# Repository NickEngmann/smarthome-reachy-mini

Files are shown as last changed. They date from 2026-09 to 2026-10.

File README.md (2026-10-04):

# smarthome-reachy-mini

Hardware for putting a smart-home display on a **Pollen Robotics / Hugging Face Reachy Mini**. The display is an **Elecrow CrowPanel Advanced 7" ESP32-P4** (1024×600 IPS touch, ESP32-C6 Wi-Fi 6). It rides on the robot's front belly in a 3D-printed enclosure dressed as denim dungarees.

The display's firmware and software live in the sibling repo **`../smarthome-reachy-mini-display`**.

## System architecture
The display is one part of a local, private assistant that replaces an Echo Show:
- **Reachy Mini** handles listening, speaking, reflexes and gestures.
- A **Jetson AGX Thor** runs speech recognition, a local LLM and speech synthesis.
- **Home Assistant** on a Raspberry Pi 5 keeps timers, weather, music and alerts.
- The **CrowPanel** is an Echo-Show-style dashboard that reads only Home Assistant.

This is the current direction, not final software decisions. It is written up in [`../smarthome-reachy-mini-display/docs/system-architecture.md`](../smarthome-reachy-mini-display/docs/system-architecture.md); the latency design is in [`docs/latency.md`](../smarthome-reachy-mini-display/docs/latency.md) in the same repo.

## Repo map

| Path | What |
|---|---|
| [`hardware/enclosure/`](hardware/enclosure/README.md) | The dungarees enclosure: cadquery source, fit, mesh and printability checks, renders, and **Bambu Studio projects ready to print** (`out/bambu/*.3mf`) |
| [`cad/`](cad/README.md) | Reference models: Reachy Mini body and robot (assembled from Pollen's URDF), Elecrow's official CrowPanel P4 STEP and STL conversions, and two community cases (the ACOS enclosure for the S3 Advance 7", and a two-part case 3MF) |
| `elecrow-crowpanel-advance-7-enclosure-model_files.zip`, `elecrow-panel.3mf` | The original community-case downloads, also unpacked under `cad/community-cases/` |
| [`docs/TODO.md`](docs/TODO.md) | Hardware ideas not built yet, with whatever has already been measured for them. First up: **a hat**, and what the antennas and the head's microphones will and will not allow |

## Print the enclosure
1. Open `hardware/enclosure/out/bambu/reachy-dungarees-tray-cradle.3mf` and `reachy-dungarees-bezel-backstrap.3mf` in Bambu Studio.
2. Load PETG and print. Both projects are set for an X1C with a textured PEI plate, 0.20 mm layers, and no supports.
3. Assemble: board into the tray, bezel snapped on, tray-cradle against the belly, backstrap slid on from behind along the side rails until it stops, then a pin dropped into the top of each side joint (the two pins print on the bezel-backstrap plate).
4. Optional: `reachy-dungarees-bib-straps.3mf` (41 min, 9.1 g, PETG) adds the two shoulder straps. They hang over the robot's own front rim and slide down behind the panel into the pocket the cradle already has, where a spring finger clamps each one against the collar band (v3 — v2 needed hot glue). They change nothing about the three parts above — see the enclosure README's "Bib straps".

Check the enclosure README's Status section before printing: it records the last verified build. It also lists the tolerances, load reasoning and open risks.

## Rebuild from source
The enclosure scripts use cadquery on the ESP-IDF 3.11 interpreter (`python`), with numpy and scipy. Bambu Studio's CLI is used for slicing. See [`hardware/enclosure/README.md`](hardware/enclosure/README.md) for the full command list.

## Licences of included third-party files
- **Reachy Mini meshes:** Pollen Robotics, CC BY-NC-SA 4.0.
- **CrowPanel STEP:** Elecrow, from their GitHub repo, which has no licence file.
- **ACOS enclosure:** Alley Cat / Majestic AV, CC BY-SA 4.0 (attribution required).

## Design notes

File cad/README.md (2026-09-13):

# CAD reference models

Reference geometry for the smarthome Reachy Mini display enclosure. All units are mm unless noted.

## `reachy-mini/` — Pollen Robotics Reachy Mini
Assembled from the per-part STLs and URDF in https://github.com/pollen-robotics/reachy_mini (`src/reachy_mini/descriptions/reachy_mini/urdf/`), at the URDF zero pose. Hardware licence CC BY-NC-SA. No official STEP has been released yet.

- `reachy_mini_body.stl` — body only: foot, turning ring, lower and upper shell
- `reachy_mini_full.stl` — whole robot
- `dimensions.txt` — per-part bounding boxes, plus body radius per 5 mm of height
- `reachy_mini_dimensions.png`, `back_interface.png` — Pollen's official drawings
- `preview.png` — render of the assembly

Frame: +X = front (camera side), +Y = robot's left, Z up, Z = 0 at the table.
Body envelope: 155 × 155 × 185. The shell is a rounded square in section: 155 across the flats, ~164 across the diagonals at z 50–100. The top edge is scalloped and highest at the front (z 184.8). The shell yaws ±180° on the foot (z 0–22, ~114 × 126).
The assembly script lives outside this repo, in `Projects/reachy-mini-cad/assemble.py`.

## `crowpanel-advanced-7in-esp32-p4/` — Elecrow CrowPanel Advanced 7" ESP32-P4 (Amazon B0H5K6W1C3)
- `ESP32-P4-7_0-inch-20251229.stp` — official Elecrow STEP, from https://github.com/Elecrow-RD/CrowPanel-Advanced-7inch-ESP32-P4-HMI-AI-Display-1024x600-IPS-Touch-Screen (`3D file/`)
- `CrowPanel-Advanced-7in-ESP32-P4.stl` — STL conversion (0.05 mm tolerance)
- `CrowPanel-Advanced-7in-ESP32-P4_no-flex-tails.stl` — same, with the flat-drawn LCD/touch flex tails clipped off above z = 53
- `dimensions.txt`, `preview.png`

Frame: X = long axis, Z = short axis, +Y = glass/viewing side, origin at board centre.
- PCB: 176.9 × 104.0 × 1.7
- LCD and touch glass: 164.9 × 100
- Active area: ~154 × 86
- Overall thickness: 17.5 (y −13.8 → +3.7)
- Mounting holes: 4 × Ø3.2 (M3) at x ±85.45, z ±49.0, i.e. **170.9 × 98.0** spacing
- Elecrow's spec lists the outline as 180 × 105, 450 g

## `community-cases/`
- `acos-crowpanel-advance-7-enclosure-s3/` — **Alley Cat "ACOS" enclosure** (Printables 1476807), CC BY-SA 4.0. It was designed for the **ESP32-S3** CrowPanel Advance 7", not the P4. Its board screw pattern (171 × 98) matches the P4's, but the port cutouts may not. Parts: front/center/rear in SMA, USB and insert variants, plus buttons and a `complete.step`; overall 197 × 111 × 25. `printables-1476807-description.pdf` has print settings and the BOM (4× M3×8, 4× M3×12, 8000 mAh LiPo).
- `crowpanel-p4-7in-case-3mf/elecrow-panel.3mf` — user-downloaded two-body case, probably Printables 1689586 ("Elecrow CrowPanel ESP32-P4 7" Case" by BIG_SUNDAR); unverified. Tray 182 × 124.5 × 20 plus a 7 mm lid.

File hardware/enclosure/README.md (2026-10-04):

# Reachy Mini dungarees: a CrowPanel 7" P4 enclosure

This is a three-part (plus two small pins), screwless, 3D-printed enclosure for the **Elecrow CrowPanel Advanced 7" ESP32-P4**. It clamps onto **Reachy Mini's front belly** and is dressed as **denim dungarees**: the display is the bib, and the collar is the waistband. It turns with the body and needs no changes to the robot. The display's software lives in the sibling repo `../smarthome-reachy-mini-display`.

The toolchain follows reMixTape (`reMixTape/re-MixedTape/hardware/enclosure`) and Luna (`luna/luna-hardware/hardware/enclosure_v2`): cadquery scripts, an interference check against the board STEP, mesh and layer checks, a Bambu Studio project writer, and headless slicing with the Bambu Studio CLI.

## Commands
Run these with `python`, the ESP-IDF 3.11 interpreter (cadquery 2.8, numpy, scipy).

```
python shell.py                  # once: Reachy shell proxy -> out/cache/
python enclosure.py              # build + export all parts (~12 min)  [--plain: no dungarees detail]
python collar.py --check-only    # fit checks on the exported STEPs (exit 1 on failure)
python check_mesh.py             # every exported STL watertight
python islands.py                # layer scan: floating islands (what the slicer calls "floating regions")
python islands.py --overhangs    # layer scan: cantilever/bridge regions with locations
python bambu.py --slice          # out/bambu/*.3mf + overhang audit + Bambu Studio CLI slice (time, grams, warnings)
python probe.py                  # diagnostic: re-slice with supports on critical regions, report where they touch
python render.py                 # out/render/*.png
python overalls.py [--check]     # the two optional bib straps (~1 min); --check-only for the fits
python render_overalls.py        # out/render/overalls-*.png
```
After a build, everything below `enclosure.py` reads only its exports, so the checks can run side by side. Run `bambu.py --slice` on its own, though: with the other checks competing for the CPU, a slice of the tray-cradle ran past 25 minutes. `python enclosure.py --check` builds and checks in one go (slower).

## Parts

| Part | Prints | Function | Dungarees detail |
|---|---|---|---|
| **bezel** | face down | Window over the active area. A full-depth top wall holds the **microSD slot**. A snap lip hangs from a shelf on the plate on three sides, with 45° bumps on the two ends. Oval bosses hold the board down, with slot sockets for the tray's locating pegs. | Dashed stitch round the bib, two bib buttons above the screen, and a heart below it. All are engraved, because a face-down print can't have raised detail. |
| **tray-cradle** | upright | The tray has **2× USB-C openings** sized for a plug's overmold and a **switch slot** on one end. The floor has **BOOT/RESET pin holes** plus LED and mic holes. Four standoffs carry **locating pegs** through the board's M3 holes, and relief channels above the USB-C windows let the connectors slide down past the wall. Behind the tray, ribs bear on the belly and the front half of the waistband ends, on each side, in a plate with two rails, a stop, and a cap with the pin hole. | A strap, buckle and engraved button on each end of the bib, a stitched waistband, belt loops and a rolled cuff. |
| **backstrap** | upright | The rest of the collar. At each side, a tongue slides onto the plate's two rails and is locked by a pin dropped through the cap into a boss on the tongue (v0.6). Three **spring tabs** preload the collar, and a **cable gutter** runs along the bottom. | Crossed back straps with edge stitching and teardrop buttons, two back pockets, a waistband with belt loops, and side buttons. The gutter doubles as the cuff. |
| **pins ×2** | head down | The side joints' locks (v0.6): Ø4 × 25 mm with an 8 mm head, dropped through the tray-cradle's cap into the backstrap's boss on each side. They print on the bezel-backstrap plate. | Copper-coloured in the renders, like jeans rivets; print them in any colour. |
| **bib-strap ×2** | on its side | **Optional, cosmetic.** Hangs over the robot's own front rim, runs down the outside of the shell, and drops into the gap behind the display, where a foot fills the pocket between two of the cradle's ribs and a spring finger clamps it in place. The other three parts are untouched. | The two shoulder straps of the dungarees, 14 × 2.1 mm with edge stitching, completing the crossed straps already moulded on the backstrap. |

## Bib straps

Two small clip-on prints (`overalls.py`), added after the first three were done. They are what makes
the robot read as *wearing* the dungarees rather than carrying a bib: from the front a strap comes
over each shoulder and disappears behind the panel. Nothing touches the bib's face, and nothing
about the bezel, tray-cradle or backstrap changes — lift the straps off and the enclosure is exactly
as it was.

```
python overalls.py [--plain]         # build and export the pair (~1 min)  [--plain: no stitching]
python overalls.py --check-only      # fit checks against the exported STEPs
python render_overalls.py            # 3-D views + sections -> out/render/overalls-*.png
python render_overalls.py --section  # just the sections (seconds: no 3-D painting)
```

`overalls-section*.png` are the pictures that actually show the fit: every part cut by a plane just
off the strap's centre and drawn filled, so the rim hook on the shell's top edge, the 1.5 mm the run
stands off the body and the spring finger's nub pressed into the collar band are geometry rather
than a claim. A 3-D render of a 2 mm strap against a curved shell cannot show a 1 mm gap. There is no tight
3-D close-up of either hook for the same reason: `render.py` depth-sorts one collection by centroid,
which breaks down at close range on the shell's coarse triangles.

Each strap is five lofted pieces unioned, sliced every 1 mm so each slice follows the body at its
own Y.

| Piece | What it does |
|---|---|
| rim hook | A loose C over the shell's top edge: a 4.5 mm slot over a ~2 mm rim, reaching 3 mm down inside. Deliberately loose — a tight slot on a rim known only from CAD is a reprint, and the foot is what holds the strap. |
| shell run | Inner face at `SHELL_CLR` (1.5 mm) off the body's front, from z 150 up to the rim. |
| gap run | Leaves the shell at z 152 and leans forward into the gap behind the panel. |
| **tongue** | Fills the slot between two of the cradle's ribs (20.0 in 20.80), 0.40 off the tray's back wall, down to 0.4 mm above the collar band's top edge (Z 124.4). Locates the strap side to side and stops it dropping. |
| **spring finger** | Outboard half only (|Y| 37.5…47.5). A 1.68 mm blade on down the tray's back wall into the slot between the wall and the collar band, to Z 92, with a nub at Z 104 pressing the band. This is what **holds** the strap. |

**v3 (2026-09-30): why the finger.** v2 was printed, and the owner had to hot-glue it in. Its two
shoulders sat on the rib tops and a short tongue hung in the slot — that *located* the strap but
nothing *held* it: there is no downward-facing ledge in the pocket to hook under, and a 3 g strap
on a turning robot walks out. The owner's sketch ran the foot on down behind the panel; v3 does that
and adds a spring, because depth alone still would not hold anything. The nub is modelled 1.2 mm
into the band: the strap first moves 0.40 forward until the tongue bears on the tray's back wall,
and the other 0.8 bends the finger. So the strap is **clamped between two faces of the tray-cradle
itself** and holds by friction. In this print orientation the finger bends along its layers, not
across them — the strong way for a printed spring.

**Where it can go, and why** (robot frame, all measured):

- **The mount is a pocket that was already there.** The ribs at |Y| 25 and 50 (4.2 thick) leave a
  slot **27.10…47.90**, 20.80 wide. Behind the tray's back wall, between those ribs, the free depth
  is 6.7 mm (inboard) to 15.7 mm (outboard) above Z 124, where the shell is what is behind it. Below
  Z 124 the collar band comes in: **1.3 mm** deep inboard, **8.8** outboard, and waisted, narrowest at
  about Z 108. Nothing was added to the cradle, and nothing about it changed.
- **Only the outboard half takes a spring.** Inboard of |Y| 37.5 the waist is under 3.95 mm, and the
  finger needs 3.28 (1.6 to bend into plus 1.68 of blade). There the tongue alone stops on the
  band's top edge.
- **The band is our own part, so it is exact.** `overalls.band_x` sections the same proxy
  `collar.band()` is made from; it agrees with an exact section of the exported STEP to 0.000 mm.
  The exported *STL* — which is what the slicer prints — sits up to **0.28 mm** inside it at the nub
  (collar.py's STL export uses cadquery's default relative tolerance, so its chords are coarse). The
  preload was raised from 0.6 to 0.8 for exactly that, and the check reports both.
- **The strap is flush with the foot's OUTBOARD edge**, centred on |Y| 40.5 (v2: inboard, 31.5).
  The finger only fits outboard, and in the print the outboard edge is the one on the plate — see
  "Print checks" below.
- **The microSD is not a constraint here.** It opens through the bezel's top wall at |Y| 62…76, well
  outboard of the strap. It *was* the constraint for the rejected front-clip version.
- **Head clearance.** Above the front rim the whole robot stays inside X 41.5…43.2 (full mesh,
  z 185…196) while the rim itself is at X 51…55 — about 12 mm of clear space just inside it. The
  measured distance from the rim hook to anything above z 184 and inboard of X 46 is **7.52 mm**.
  That is Pollen's CAD in the URDF zero pose, **not a measured head sweep**: check it on the robot.

**Rejected on the way**, so it is not tried again: straps clipped to the *front* of the bib and
rising above the display. The display's top corners sit 43 mm in front of the body, so such a strap
either spans that gap as a strut or stops in mid-air — three variants were built and rendered, and
none read as a strap from the side. Straps hanging *below* the display have nowhere to go either:
the enclosure's cuff ends at z 30 and the robot's turning foot starts at z 22, and the foot does not
yaw with the body.

## Printing (Bambu Lab X1C)

The three projects are ready to open in Bambu Studio: `out/bambu/*.3mf`. Settings start from your saved X1C project (`bambu/project_settings.json`, taken from luna-hardware): 0.4 mm nozzle, textured PEI, 0.20 mm Standard. Filament is Bambu's own **PETG Basic @BBL X1C** preset.

| Project | Plate | Per-part settings |
|---|---|---|
| `reachy-dungarees-tray-cradle.3mf` | the tray-cradle upright, as it sits on the robot | 5 mm outer brim |
| `reachy-dungarees-bezel-backstrap.3mf` | the bezel face down (textured PEI gives the bib a fabric-like finish), with the backstrap upright and turned 90° beside it | backstrap: 5 mm outer brim |
| `reachy-dungarees-bib-straps.3mf` | both bib straps on their sides, profile flat on the plate and the Y width as the print Z (each turned so **its own** flush edge is down) | 8 mm outer brim each; first layer 25 mm/s at 255 °C, textured plate 80 °C for the first layer and 75 °C after (adhesion — see below) |

`bambu.py --only <substring>` writes and slices just the projects whose name matches, so a change
to one plate does not re-time the others.

Common process settings:
- **Walls and infill:** 3 walls (the collar band is solid), 5 top and 4 bottom layers, 20 % gyroid.
- **Seam and ironing:** aligned seams, no ironing.
- **Supports:** none anywhere.
- **Elephant foot:** 0.15 mm compensation, so the engraving and the joint's sliding faces stay clean.
- **Bib straps, first-layer adhesion (2026-09-30).** The first v3 print would not stay on the plate
  and the PETG built up on the nozzle, with dry filament (6 % in the box), flow calibration and bed
  levelling all on. Each strap stands on a 284 mm² footprint of thin perimeters, so a line that
  does not bond gets dragged onto the nozzle. That plate alone now prints its first layer at
  25 mm/s (was 50, and 105 for its infill) and 255 °C (the preset's 245 was the coldest layer of the
  print), on a textured plate at 80 °C for the first layer and 75 °C after (preset 70), with an 8 mm
  brim (was 5). Before changing anything, wash the plate with dish soap and water and brush the
  nozzle clean while hot; if it still lifts, add a thin layer of glue stick. The straps have since been
  printed and work (owner, 2026-09-30).

Latest CLI slice:

| Project | Time | PETG | Supports | Slicer warning |
|---|---|---|---|---|
| tray-cradle (v0.6) | 5 h 14 | 162.5 g | none | none |
| bezel + backstrap + 2 joint pins (v0.6) | 4 h 00 | 124.1 g | none | none |
| bib straps (both, v3) | 41 min | 9.1 g | none | none |

**Colour:** a denim-blue PETG. With an AMS, add a height-range filament change on the upright parts for a brown cuff (z 0–4) and waistband (z 32–48 on the plate).

### Print checks and what they changed
Every geometry change is checked four ways: the fit check, `check_mesh.py`, `islands.py` (floating islands, then overhang regions), and a Bambu Studio CLI slice. `probe.py` turns support on for critical regions only and reports where the slicer puts it, which is how its warnings were traced to a part and a height. Fixes made for printing:

- **Bezel lip shelf.** The lip used to hang from the parting plane with a 2.4 mm gap to the plate, held only by the top wall and bosses. Face down, it would have printed as one long bridge in mid-air. It now hangs from a shelf on the plate.
- **BOOT/RESET flex tabs** (since replaced by pin holes, see v0.5). Rooted at the side, their lower edge was a 10 mm cantilever over the slit; that was the tray-cradle's slicer warning.
- **Spring tabs.** The slot and the tab close at the top in a 45° point instead of a flat top slit. The flat slit's roof was a 15 mm curved bridge, 2.5 mm thick with air on both faces, and Bambu Studio flagged it as a "floating cantilever" on the backstrap. `bisect_backstrap.py` found it in two rounds:
  - Round 1: of six variants with one feature group removed, only the one without springs sliced clean.
  - Round 2: flat springs without their nubs still warned, while gable-topped springs with nubs sliced clean.

  The back belt loops moved to 150° and 210° to clear the points.
- **Side buttons.** They are sunk 1 mm into the tongue and shaped as teardrops. At 0.3 mm deep their lowest layers floated; that was the backstrap's "floating regions" warning.
- **Other 45° undersides:** joint hooks (with windows 0.6 mm taller to clear them), teardrop strap buttons, pointed strap ends, a half step under the belt loops, pocket points, overmold recess roofs, and a wedge under the buckle frame. Buckle buttons are now engraved.
- **Mesh fixes:** the collar band stops 0.4 mm behind the tray back, and the tray-end straps no longer touch the button or the tray top. Each of these left faces that only touched, which meshed with non-manifold edges.
- **Fit review before the first print (v0.4).**
  - **Board location:** the locating pegs moved from the bezel to the tray standoffs. With the pegs on the bezel, the board could float ±1.1 mm while hidden pegs, which capture only about 0.7 mm, had to find its holes.
  - **USB-C:** relief channels added above the windows. The shells stood 0.1 mm from the wall while the board went in.
  - **Clearances:** boss-to-board gap 0.2 → 0.4, top-edge clearance 1.5 → 2.0 and collar-to-shell 1.5 (was 1.0).
  - **Snap engagement:** bump engagement 0.45 → 0.40.
  - **Flexures:** slits 0.84 → 1.0 with 45° pointed tops on every flexure; BOOT/RESET tabs thinned to 0.84 mm (about 12 N → 4 N).
  - **Spring nubs:** chamfered on all four sides.
  - **New checks:** `collar.py --check-only` now also checks the assembly paths, not only final positions: the board lifted out of the tray, the tray-cradle backed off the belly, and the backstrap pulled back off the robot and the tray-cradle.
- **Independent fit review (v0.5).** A second reviewer went over v0.4 for anything that would force a reprint. Changes:
  - **Snap bumps:** the bottom bumps are gone. The tray's bottom wall is fused to the cradle filler and can't flex, so a bump there would have strained the lip about 15 %; the bottom lip now only locates. There are five bumps on the two end walls instead (z ±40 and 0 on the right, clear of the USB-C openings and the switch). Both faces are 45°, so the bezel pulls off without prying. The pockets let the bezel lift 0.3 mm (was 0.6).
  - **BOOT/RESET:** Ø3 pin holes with a countersink, pressed with a paperclip. The flex tabs bent across the layer lines at 4–6 % strain, and a pointed slot top left a 0.7 mm web between the two tabs.
  - **USB-C:** the overmold opening (14 × 8.2) runs through the whole wall, so a plug seats fully. The blind recess stopped the overmold 0.8 mm short and left a 0.1 mm web.
  - **Pegs and sockets:** pegs go 1.4 mm past the board (was 2.4). The bezel sockets are 3.4 × 4.2 slots in 5.0 × 5.8 oval bosses. Face down, the bezel shrinks in its own plane while the upright tray's hole pitch doesn't, so round sockets could have ridden up onto the peg points. The boss-to-board gap is back to 0.2: the board thickness was already in the stack-up.
  - **Spring preload:** the nubs reach 1.2 mm plus the play the collar loses as it seats (1.9 mm at the back, 1.55 mm at 120°/240°). Tabs are 1.26 thick and 25 mm long, so the remaining 1.2 mm is about 0.6 % strain.
  - **microSD:** the slot is 12 × 1.6 with a 45° lead-in, so a card can't drop into the case (was 13.4 × 3.2).
  - **Mics:** Ø2.0 teardrop holes (Ø1.2 prints closed).
  - **Lead-ins:** a 0.4 mm chamfer on the bezel lip's free edge, and 0.8 mm chamfers where the tongue meets the strip. The joint pull lips are 0.84 mm proud (was 1.68): only 0.6 mm of lift releases a hook.
  - **Mesh:** the right back strap's edge stitches ended 0.1 mm inside its button and tore the mesh (794 open edges). They now stop 1.5 mm above it. Waistband stitch dashes keep clear of the spring slots.
  - **Checks:** the path sweeps now run the backstrap 100 mm back and the tray-cradle 60 mm off the belly in finer steps, and add the bezel lifted off the tray and board.
- **Plate placement.** The print STLs are set on the plate by their tessellated vertices. OCC's bounding box of the lofted collar was loose, and the STLs floated.

## Load: why it stays put
- **The load is small.** The display (≤450 g) plus the enclosure (~260 g PETG) sits about 20 mm in front of where the ribs bear on the belly. Stopping it tipping forward takes only about 2 N at the collar top.
- **It can't slide.** The collar runs from z 30 to z 124, across the belly's widest ring (r 77.4 at z 60). It is 3 mm narrower above (r 74.3 at z 120) and 4 mm narrower below (r 73.4 at z 30), so it can't pass the bulge either way.
- **The side joints are a rail-and-pin slide lock (v0.6).** v0.5's flex-tab hooks never clicked when printed and the joint had to be glued (owner, 2026-09-30); nothing in v0.6 has to flex.
  - Each side of the tray-cradle ends in a 2.1 mm plate with two rails (z 70 and 100) running along x. The backstrap's 2.94 mm tongue has matching grooves on its inner face, open at its front edge. A 2 mm funnel at each groove's mouth and a 45° taper on each rail's rear end let a rail find its groove from 2 mm out of line. The rails set the tongue's height and keep it on the plate.
  - The backstrap slides forward until the tongue's front edge meets a stop on the tray-cradle. There the two halves of a vertical hole line up: through a cap on the tray-cradle, above the band, and down into a boss on the tongue.
  - A Ø4 PETG pin dropped into that hole on each side is the lock. The collar's pull (the spring nubs push the backstrap back) goes through the pins, in shear. Pull the pins to take the backstrap off.
  - The rails are trapezoids, not dovetails, because of the upright print. A dovetail groove's roof would start at the tongue's face with nothing under it, a floating sliver the length of the groove. The tongue still can't leave its plate: the whole backstrap would have to move sideways, and its other tongue is up against the other plate.
  - Every joint surface is still extruded along x, so the backstrap slides straight on.
- **Spring preload.** Three U-slot spring tabs press their nubs into the shell. They reach 1.2 mm plus the play the collar loses as it seats, so about 1.2 mm of preload remains once seated. The nubs have 45° sides all round, so they ride up onto the shell as the backstrap slides on instead of catching on an edge. The ribs seat on the belly, and the collar's 1.5 mm clearance never becomes rattle.
- **Remaining limit:** at full body yaw, the display's front corners sweep a radius of about 135 mm, and the extra mass makes body turns slower.

## Tolerances: Bambu X1C, 0.4 mm nozzle, 0.20 mm layers, PETG
Every fit is one of these classes (`geom.py`). Walls are whole line widths (`lines(n)` × 0.42 mm), and heights stacked in a part's print Z are whole layers (`layers()`).

| Class | Value | Used for |
|---|---|---|
| `FIT_SNAP` | 0.40 / side | Bezel lip to tray wall (reMixTape printed 0.2 on this printer; +0.2 wiggle room). Bumps are 0.80 with 45° faces both ways, so they engage 0.40 past the wall face, as on reMixTape. Pockets are +0.3 deep and +1.6 wide. |
| `FIT_SLIDE` | 0.40 / side | Faces that slide past each other |
| `FIT_JOINT` | 0.50 / side | The side joint (v0.6): tongue over the side plate, each rail in its groove (normal to every face), the tongue's boss under the tray-cradle's cap. `FIT_SLIDE` + 0.1, because these are 94 mm tall, thin, curved walls printed upright, which warp more than the bezel lip `FIT_SLIDE` was proven on, and v0.5's 0.40 joint never went together. The pin locks the joint, so play in the rails costs nothing. |
| Joint pin | Ø4.0 pin in a Ø4.8 vertical hole | 0.4 a side, so a pin drops in even when the two parts sit 0.4 mm out of line sideways. The stop leaves the two halves of the hole 0.2 past alignment, well inside that. |
| `FIT_Z` | 0.40 (2 layers) | Any gap across layers: glass to bezel plate, lip to PCB, tray top to bezel top wall |
| `FIT_CATCH` | 0.30 | Play at the bezel's snap catch face |
| `HOLE_H_EXTRA` | +0.30 | Holes lying flat in an upright print get a teardrop roof; pins lying flat are teardrops, point down. |
| Locating pegs | Ø2.4 teardrop pins on the tray standoffs (point clipped to R1.45, 1.4 mm past the board, 45° tip); 3.4 × 4.2 slot sockets (long in z) in 5.0 × 5.8 oval bezel bosses | 0.4 / side in the board's Ø3.2 holes. The board sits on its pegs before the bezel goes on, so nothing has to find a hidden hole. The slots absorb the face-down bezel's in-plane shrink. |
| Boss to board | 0.2 (1 layer) | Holds the board down without rattle |
| Board to wall | 0.75 / 1.1 / 2.0 | Sides / USB-C end (plus 0.6 × 9.4 mm relief channels above the USB-C openings, so the connectors, which stand 1.0 mm past the board edge, slide past the wall) / top edge (the flex cables wrap it; was 1.5) |
| Flexure slits | 1.0, 45° pointed tops | Spring tabs: no bridged slit roof sits above a flexure where it could sag and fuse (was 0.84) |
| Shell | 1.5 collar, 0.4 ribs | The shell is Pollen's CAD mesh, not measured on the robot, and a tight collar would mean a reprint (was 1.0). The ribs set the position and the springs remove the play. |
| Openings | USB-C 14 × 8.2 through the wall (R2.2), switch 11 × 5.6, microSD 12 × 1.6 with a 0.8 lead-in, BOOT/RESET Ø3.0 (countersunk Ø4.6), mics Ø2.0 teardrop | |
| Lead-ins | 0.4 × 45° on the bezel lip's free edge; 0.8 × 45° on the side plate's rear outer edge and the tongue's front inner edge; 2.0 × 45° funnels at the groove mouths and 2.0 × 45° tapers on the rails' rear ends; 0.6 countersink on the pin holes and chamfer on the pin tips | |
| Walls | tray 2.1 (5 lines), collar 2.52 (6), tongue 2.94 (7), side plate 2.1 (5), ribs 4.2 (10); 1.68 (4) round each pin hole | |
| Detail, upright | proud 0.84 / 1.26 / 1.68; grooves 0.84 × 0.5 deep; stitch dashes 0.8 tall (4 layers); every underside at 45° or steeper | |
| Detail, bezel face | engraved 1.0 wide × 0.6 deep | |

## Assembly
1. Lower the board, glass up, onto the tray's four locating pegs. Start at the USB-C end, so the connectors slide down the relief channels into their windows. The board then sits on its standoffs without moving.
2. Press the bezel on at the bench, before the tray-cradle goes on the robot, until the bumps click. Its boss sockets drop over the peg tips. To open it, pull it straight off: the bumps are 45° both ways. The notch at the bottom centre gives a fingernail a start.
3. Put the tray-cradle against Reachy's belly. The front half of the waistband slides on from the front.
4. Slide the backstrap on from behind, level, so the tongues pass outside the tray-cradle's side plates. The grooves' funnels catch the rails; push it forward until the tongues stop (the spring nubs drag on the shell on the way). Holding it there, drop a pin into the hole on top of each side, head up.
5. To take it off, pull the two pins and slide the backstrap back.
6. **Bib straps, if you printed them.** Last, and by hand. Slide each one down the back of the
   tray, finger first, into the slot between the ribs — the chamfers find the slot — and keep
   pushing down along the tray's back wall. The nub rides over the collar band's top edge (the finger
   bends about 1.3 mm) and the strap stops when the tongue reaches the band. The rim hook drops over
   the shell's front rim on the way down. To remove, pull it straight up along the tray's back wall.
   They come off before the bezel does.

Cable:
- **Outside power:** plug either USB-C port directly.
- **From Reachy:** lay the cable in the back gutter and down to the foot port, with slack for the body's ±180° yaw.

## Frames
- **Board frame B** is Elecrow's STEP frame: x long, +y is the glass side, z is up.
- **Robot frame R**: +X front, +Y robot's left, Z up, 0 at the table.
- The transform is R = T(X0,0,Z0)·Ry(−6°)·Rz(−90°)·B. `placement()` puts the tray's lowest back edge at z 30, with the tray back 2.5 mm from the shell at the closest point. Board centre: robot X 97.4, Z 86.3.

## Status (2026-09-30, v0.6: rail-and-pin side joints, not yet printed)
v0.5 was printed. Its bezel, tray and collar fit, but its side joints never clicked: the hooks on
the tongues' hidden inner faces never caught in the strip's windows, and the joint had to be glued
(owner). v0.6 replaces the joint with rails, a stop and a drop-in pin on each side. Everything else
is unchanged. The run was `enclosure.py --check`, then `collar.py --check-only` (after fixing one
check), `check_mesh.py`, `islands.py` (both modes) and `render.py`, then `bambu.py --only … --slice`
on each plate on its own. **Everything passes, and both plates slice with no warnings and no supports.**

| Part | Volume | Robot-frame extent (mm) | Checks |
|---|---|---|---|
| bezel | 26.0 cm³ | x 74.7…107.4, y −91.3…91.6, z 31.8…142.5 | unchanged; clear of all 55 board solids; watertight |
| tray-cradle | 144.6 cm³ | x −16.0…103.1, y −92.6…92.9, z 30.0…139.6 | clear of board; watertight; no floating islands |
| backstrap | 82.8 cm³ | x −86.5…11.2, y ±88.2, z 30.0…134.3 | watertight; no floating islands |
| pins (2) | 0.8 cm³ | x −6.0…2.0, y ±88.1, z 112.6…139.6 (as fitted) | watertight; no islands, no overhang regions |

- **Fit check: passed.** 0.000 mm³ for bezel/tray, tray-cradle/backstrap, bezel/backstrap, each part against the shell, and the pins against both parts. The spring nubs overlap the shell by 119.7 mm³ (was 82.6), because they now also reach across the pin's 0.8 mm of play.
- **Assembly paths: passed.** Board and bezel as before, and the tray-cradle backs 1–60 mm off the belly. The backstrap pulls 0.5–100 mm back along the rails, past the shell and the tray-cradle, with 0.000 mm³ at every step.
- **Positive controls.** These prove the zero readings above can see contact at all:
  - Pushed 0.4 mm forward of seated, the backstrap meets the stop (80.7 mm³).
  - A rod 0.3 mm wider than the pin hole hits both parts (59.2 mm³ tray-cradle, 169.6 mm³ backstrap), so the pin really passes through both.
  - The pins lift 2–30 mm straight out without touching anything.
- **Mesh check: passed.** All twelve STLs (as modelled and as printed, the pins and bib straps included) have 0 open edges and 100 % normals.
- **Island scan: clean** on every part. In the overhang scan, the tray-cradle's regions are the same nine ≤1.8 mm ledges as v0.5. The backstrap has one 0.8 mm-reach, 1.2 mm² region at each lower groove's mouth, and the slicer did not flag it.
- **One check fixed on the way.** The "pin passes through the part" control first grew the *pin* by 0.3 mm. That still fits a Ø4.8 hole, so it read 0 and failed. It now grows the *hole* by 0.3 mm.

| Project | Time | PETG | Supports | Slicer warnings |
|---|---|---|---|---|
| `reachy-dungarees-tray-cradle.3mf` | 5 h 14 | 162.5 g | none | none |
| `reachy-dungarees-bezel-backstrap.3mf` (with the two pins) | 4 h 00 | 124.1 g | none | none |

Total: about 9 h 14 and 287 g of PETG (v0.5: 8 h 34, 266 g). Both plates must be reprinted: both halves of the joint changed.

## Previous status (2026-09-13, v0.5, printed; side joints did not work)
Final run after the independent fit review (`enclosure.py`, then `collar.py --check-only`, `check_mesh.py`, `islands.py`, `bambu.py` and `render.py`, then `bambu.py --slice` on its own): **everything passes, and both plates slice with no warnings and no supports.**

| Part | Volume | Robot-frame extent (mm) | Checks |
|---|---|---|---|
| bezel | 26.0 cm³ | x 74.7…107.4, y −91.3…91.6, z 31.8…142.5 | clear of all 55 board solids; watertight; no floating islands |
| tray-cradle | 134.9 cm³ | x −16.0…103.1, y −92.6…92.9, z 30.0…139.6 | clear of board; watertight; no floating islands |
| backstrap | 73.5 cm³ | x −86.5…11.2, y ±84.2, z 30.0…125.0 | watertight; no floating islands, no cantilever or bridge regions |

- **Fit check: passed.** Overlaps are 0.000 mm³ for bezel/tray, tray-cradle/backstrap (the hooks sit in their windows), bezel/backstrap, and each part against the shell. The spring nubs' 82.6 mm³ overlap with the shell is the intended preload plus the seating play.
- **Assembly paths: passed** at every step: the board lifted 0.5–16 mm out of the tray, the bezel (bumps removed) lifted 0.5–8 mm off the tray and board, the tray-cradle backed 1–60 mm off the belly, and the backstrap pulled 1–100 mm back past the shell and the tray-cradle.
- **Mesh check: passed.** All six STLs (as modelled and as printed) have 0 open edges and 100 % consistent normals.
- **Island scan: clean** on all three parts. The overhang scan's remaining regions are short bridges (1–6 mm: the microSD slot roof, the pry notch, loop steps), which PETG prints unsupported.

| Project | Time | PETG | Supports | Slicer warnings |
|---|---|---|---|---|
| `reachy-dungarees-tray-cradle.3mf` | 4 h 52 | 152 g | none | none |
| `reachy-dungarees-bezel-backstrap.3mf` | 3 h 42 | 114 g | none | none |

Total: about 8 h 34 and 266 g of PETG.

### Bib straps (2026-09-30, v3 — PRINTED and working, no glue (owner, 2026-09-30); v2 needed hot glue)
Added without touching the three parts above: `overalls.py`, then `overalls.py --check-only`,
`check_mesh.py`, `islands.py`, `islands.py --overhangs`, `bambu.py --only bib-straps --slice`.
**Everything passes and the plate slices with no warnings and no supports.**

| Part | Volume | Robot-frame extent (mm) | Checks |
|---|---|---|---|
| bib-strap-left | 4.01 cm³ | x 44.2…78.1, y 27.5…47.5, z 92.0…183.7 | watertight; no floating islands |
| bib-strap-right | 4.01 cm³ | mirrored in y | identical — it is the left one mirrored, not a second build |

- **Fit check: passed**, with the nub (the intended preload) taken off first: 0.000 mm³ against
  the bezel, the tray-cradle and the backstrap on both sides, and 0.000 mm³ against the shell proxy
  below z 139. The nub itself is **33.92 mm³** into the collar band on each side.
- **The spring**, per 1 mm slice across the finger: presses **0.80 mm** once seated against the
  band as designed, **0.54–0.73 mm** against the band as printed (its STL). Going in, the finger bends
  at most **1.27 mm** of the 1.60 it has, ~0.58 % strain at the root (1.68 thick, 23.4 mm lever;
  PETG's stiffness is an estimate).
- **Assembly path: passed.** The strap, nub off, moved 1–50 mm out along the tray's back wall:
  0.000 mm³ against every part and 0 points inside the shell wall at every step, both sides.
- **Against the body above the display**, measured point-to-triangle on Pollen's mesh: the run's
  closest approach is **0.81 mm** (0 of 3,616 points inside the shell wall) and the rim hook's is
  **0.64 mm** (0 of 924). The rim hook to anything above z 184 and inboard of X 46 is **7.52 mm**.
  (The run is closer than v2's 1.23 because the strap moved 9 mm outboard; its floor is 0.20.)
- **Mesh check: passed.** All four strap STLs, 0 open edges, 100 % normals.
- **Island scan: clean.** 57 mm² over 45° and 284 mm² on the plate per strap. `islands.py
  --overhangs` lists one 21.7 mm² "bridge" per strap at print z 9.7, and it is the checker's own
  artefact: layer 9.5 lies exactly on a loft station (|Y| 38.0), where the section drops part of
  the gap run (6,011 raster cells there, ~6,585 at 9.49 and 9.51), so the next layer looks unsupported.
  Bambu's slice has no warning.
- **Sections**: `overalls-section.png` (rim hook to finger tip, one closed loop),
  `overalls-section-foot.png` (the finger and its nub in the band), `overalls-section-tongue.png`
  (inboard, the tongue over the band's top edge), and `overalls-cutaway*.png` in 3-D.

**Two check bugs found on the way, worth not repeating.** The right side's cradle clip came back
from OCC *empty* for whole-number bounds (0.0 mm³ against 13,953 on the left), with no error, so the
right strap "passed" against nothing; the clip is off-grid now and the check fails if a clip is
empty. And a nub-removal tool traced along the nub's own ramps left slivers of both ramps behind,
read as 0.72 mm³ of interference; the tool is now a generous block behind the blade.

**Print checks and what they changed (bib straps).** The part prints as a prism extruded along
robot Y, so **robot Y is the print's vertical** — which inverts the intuition about overhangs. v2
cost two rounds, and v3 kept the lesson (strap, tongue and finger are all flush with the OUTBOARD
edge, which goes on the plate, and the part only loses material going up):

- **The foot is 26 mm wide and the strap 14.** Centred, the strap's whole outline — the run and
  the rim hook, 50 mm of it — began 6 mm above the plate with nothing under it: "floating
  cantilever", 214 mm² of overhang and **20 mm² on the plate**. The strap is now flush with the
  foot's inboard edge, so every outline starts at the plate and the part only loses material going
  up: 44 mm² of overhang, 135 mm² on the plate. Each side is turned so its own flush edge is down.
- **The tongue's side taper was 81° in the part and 8° in the print.** A side that drops 10 mm over
  1.5 mm of Y looks nearly vertical in CAD; in the print it crosses 10 mm of plate while the nozzle
  rises 1.5. Still a cantilever, 8.4 mm of reach. The tongue is now a 45° wedge — 1 mm of drop per
  1 mm of width, 6 mm deep, the full 20 mm across at the rib plane and 8 mm at the bottom.

Neither showed up in `islands.py`, which reported CLEAN both times: it finds regions with nothing
at all beneath them, and these had a sliver of contact. The slicer's own warning found both.

| Project | Time | PETG | Supports | Slicer warnings |
|---|---|---|---|---|
| `reachy-dungarees-bib-straps.3mf` (v3) | 41 min | 9.1 g | none | none |

**2026-09-20, handover check.** `check_mesh.py` re-run against the exports exactly as they stand:
all six STLs pass, 0 open edges, normals 100 % (backstrap 74.69 cm³, bezel 25.99, tray-cradle
135.34). The printable results are now **committed** - `out/print/*.stl`, `out/bambu/*.3mf` and
`out/render/*.png` - so the repo can be printed from without a 12-minute rebuild; `out/step`,
`out/stl` and the slicer diagnostics stay out of git, as `.gitignore` says. Nothing was reprinted or
re-sliced, and v0.5 still has never been printed.

## Open risks — check on the first print
- **Collar and spring feel.** If the backstrap is too hard to slide on, reduce `PRELOAD`; if the collar is loose, raise it.
- **Side joint (v0.6), not yet printed.** Every sliding face has 0.5 mm of clearance (`FIT_JOINT`) and the pin 0.4 a side, chosen for warp in the tall upright walls, not measured. If the tongues bind on the rails, raise `FIT_JOINT` by 0.1. If the pin holes don't line up when the tongue is at its stop, the stop is `STOP_X`. The pins hold by gravity; if one ever works up, a drop of glue on its head is fine, because the pin is the only part you take out.
- **Slide switch (MST22D18G2):** the actuator sits 1.35 mm inside the board edge, so it needs a fingernail or pen tip. A captive slider cap would be a v2.
- **microSD** is push-push, about 4 mm inside the wall, so a pen tip may be needed.
- **BOOT/RESET** are pressed through Ø3 pin holes with a paperclip or SIM tool.
- **Bezel retention.** Five 45° bumps hold the bezel by friction and flex, not by a hard catch. If it comes off too easily, raise `BUMP_D` by 0.1.
- **Mics:** their port side isn't known, so there are holes front and back.
- **The optional camera module** isn't accommodated.
- **Antennas:** by Pollen's sleep-pose drawing, the antennas pass about 14 mm outside the collar top. Check this on the robot.
- **Reachy's USB-C output:** check it supplies enough current for the display before relying on it.
- **Bib straps and the head.** The rim hook sits 7.52 mm from anything above the rim *in the URDF
  zero pose*. The head moves on its Stewart platform and this has not been checked against a real
  sweep. Watch it once with the straps on before leaving them there; if the head does come near,
  `RIM_DN` and `RIM_SLOT` set how far the hook reaches inside the rim. The front rim is the highest
  point of the body (z 184.8, against 139 at the sides), which is the reason to expect it is fine.
- **Bib strap retention (v3).** Printed and holding without glue (owner, 2026-09-30). v3 is held by the spring finger's friction, and
  how much it presses is the one number printing can move: 0.80 mm as designed, 0.54–0.73 against
  the tray-cradle's printed mesh, before any print tolerance. If a strap still lifts out,
  raise `FINGER_PRELOAD` by 0.2. The check fails once the bend going in passes 1.4 of the finger's
  1.6 mm of room. If a strap is too hard to push home, lower it by 0.2. If a foot will not
  enter the slot, `FOOT_W` (20.0 in a 20.80 slot) is the number to shave. PETG's stiffness here
  (~2 GPa) is an estimate, not a datasheet figure.
- **The straps assume the shell's real rim matches Pollen's mesh.** The slot is 4.5 mm over a rim
  measured at ~2 mm for exactly that reason, but a much thicker rim would stop the hook seating.

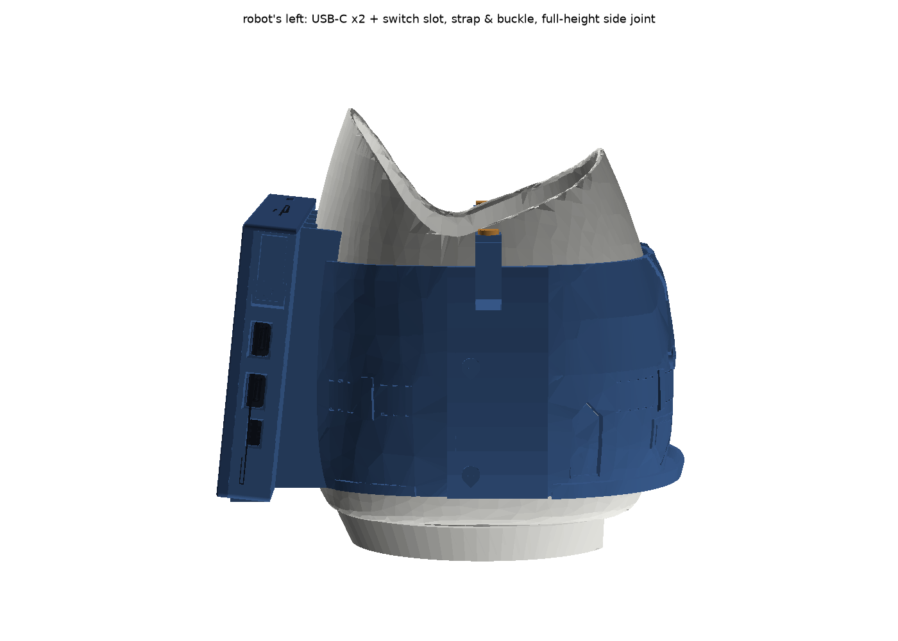
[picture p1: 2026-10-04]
hardware/enclosure/out/render/side-usb.png

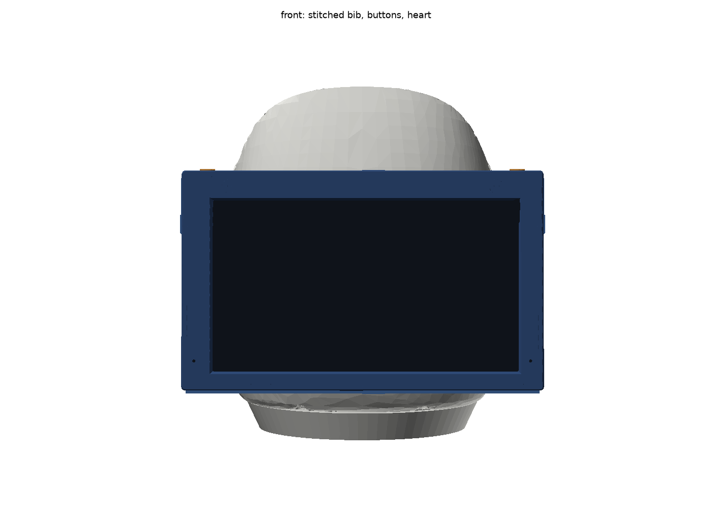
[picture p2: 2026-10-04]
hardware/enclosure/out/render/front.png

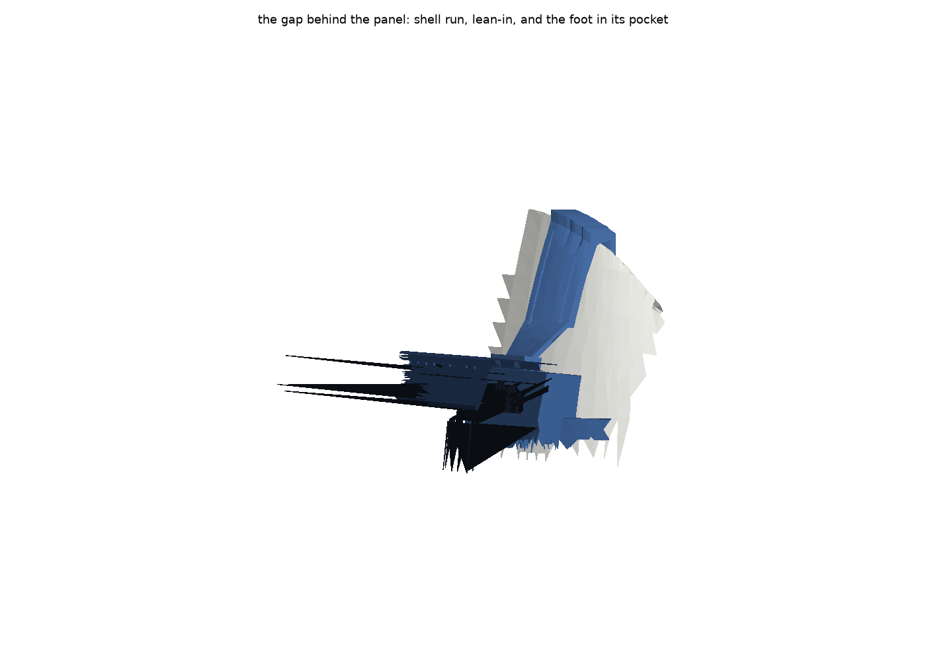
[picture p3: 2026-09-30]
hardware/enclosure/out/render/overalls-gap.png

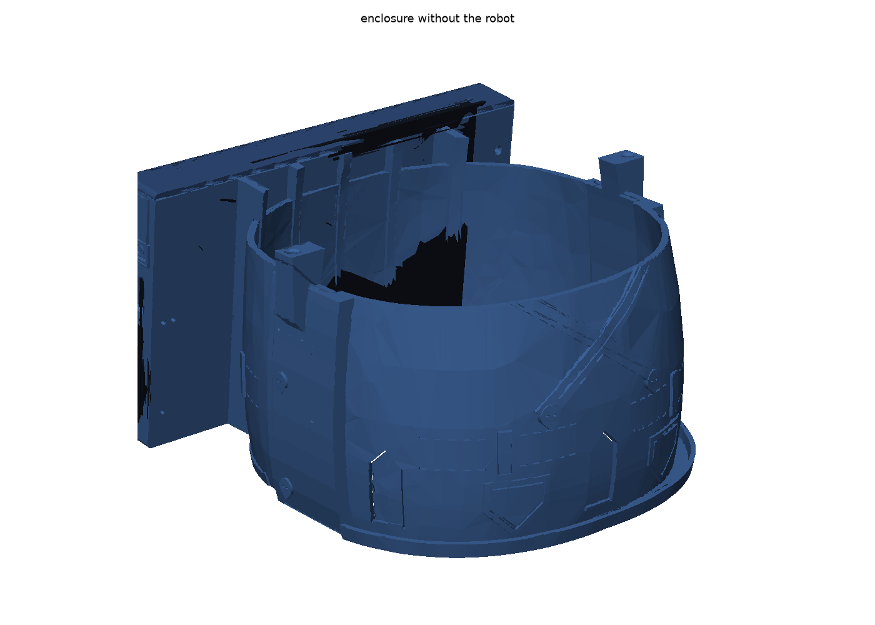
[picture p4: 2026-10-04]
hardware/enclosure/out/render/enclosure-only.png

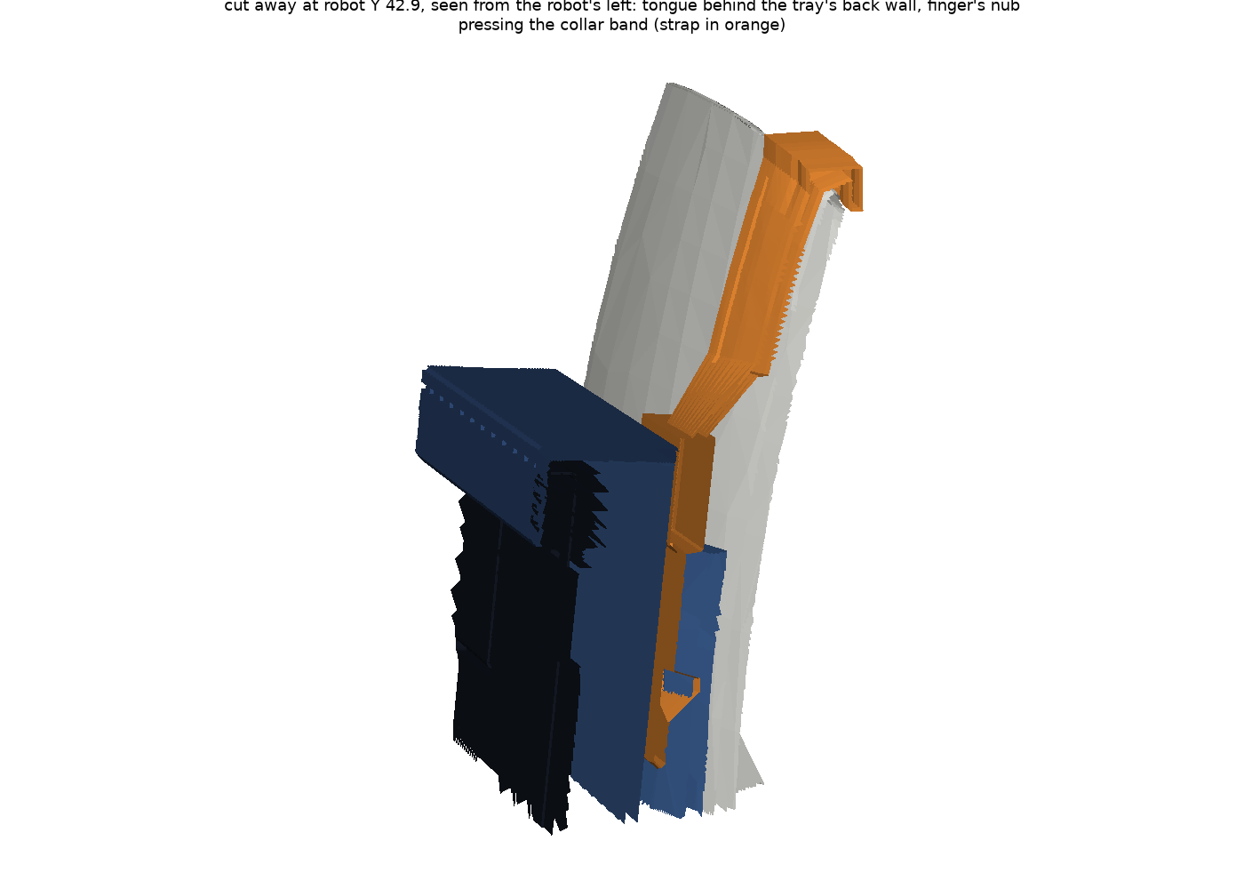
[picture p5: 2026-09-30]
hardware/enclosure/out/render/overalls-cutaway.png

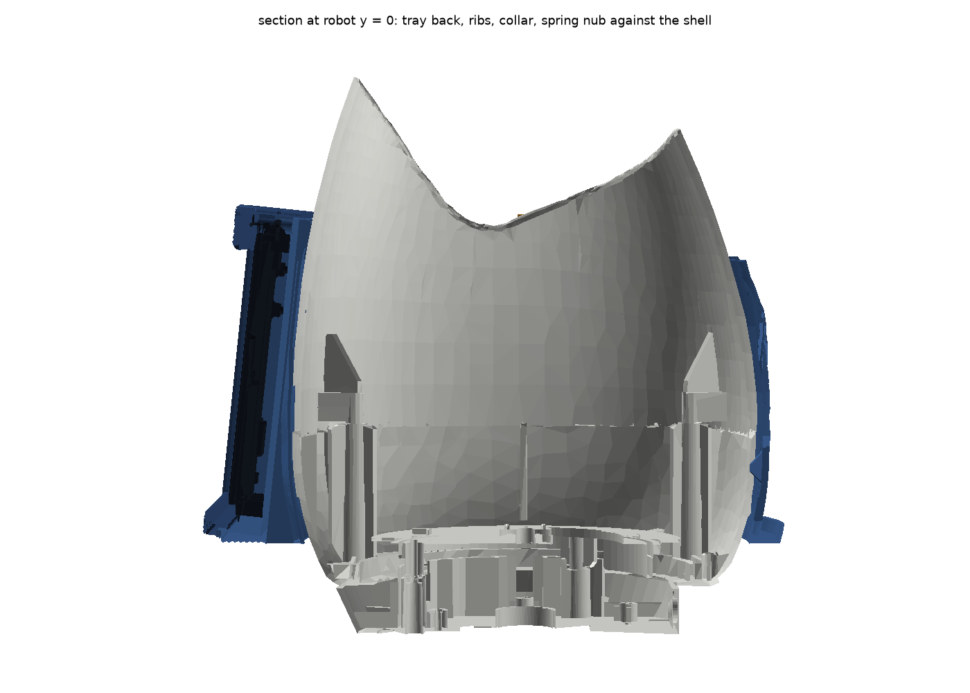
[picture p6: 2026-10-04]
hardware/enclosure/out/render/section.png

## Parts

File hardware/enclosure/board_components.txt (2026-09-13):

AS-AG638A32M1-25 -> AS-AG638A32M1-25                         size   12.50 x  11.00 x   25.25  x[  -6.25,   6.25] y[ -7.30,  3.70] z[ -68.75, -43.50]
=>[0:1:1:10] -> SOLID                                        size  176.90 x   1.70 x  104.00  x[ -88.45,  88.45] y[ -5.70, -4.00] z[ -52.00,  52.00]
U4_CONN-SMD_4P-P2_00 -> U4_CONN-SMD_4P-P2_00                 size   12.00 x   8.40 x    6.21  x[  42.45,  54.45] y[-13.80, -5.40] z[ -50.01, -43.80]
U4_CONN-SMD_4P-P2_00 -> U4_CONN-SMD_4P-P2_00                 size   12.00 x   8.40 x    6.21  x[  64.45,  76.45] y[-13.80, -5.40] z[ -50.01, -43.80]
=>[0:1:1:3] -> SOLID                                         size  164.90 x   3.50 x  155.00  x[ -82.45,  82.45] y[ -3.50,  0.00] z[ -50.00, 105.00]
=>[0:1:1:6] -> SOLID                                         size  164.90 x   1.50 x  200.50  x[ -82.45,  82.45] y[  0.50,  2.00] z[ -50.00, 150.50]
=>[0:1:1:4] -> COMPOUND                                      size  160.90 x   4.88 x   98.50  x[ -80.45,  80.45] y[ -5.70, -0.82] z[ -48.00,  50.50]
=>[0:1:1:7] -> COMPOUND                                      size  160.90 x   7.50 x   99.00  x[ -80.45,  80.45] y[ -5.70,  1.80] z[ -48.00,  51.00]
FPC1_FPC-SMD_P0_50-24P_QCHF-SM -> FPC1_FPC-SMD_P0_50-24P_QCH size   15.60 x   2.01 x    5.80  x[  -7.80,   7.80] y[ -7.66, -5.65] z[ -46.36, -40.56]
=>[0:1:1:11] -> COMPOUND                                     size   51.81 x   8.53 x   93.53  x[ -44.46,   7.34] y[ -6.71,  1.81] z[ -42.51,  51.01]
7CUN-TP-XIAN -> 7CUN-TP-XIAN                                 size   14.00 x   7.90 x   93.70  x[ -44.45, -30.45] y[ -5.90,  2.00] z[ -42.50,  51.20]
MIC-SMD_6P-L4_7-W3_8-P1_65-TL_M -> MIC-SMD_6P-L4_7-W3_8-P1_6 size    4.72 x   1.26 x    3.76  x[ -87.45, -82.73] y[ -6.96, -5.70] z[ -42.00, -38.24]
MIC-SMD_6P-L4_7-W3_8-P1_65-TL_M -> MIC-SMD_6P-L4_7-W3_8-P1_6 size    4.72 x   1.26 x    3.76  x[  82.73,  87.45] y[ -6.96, -5.70] z[ -42.00, -38.24]
WIFIM-SMD_61P-L16_6-W13_2-P0_80 -> WIFIM-SMD_61P-L16_6-W13_2 size   16.60 x   2.51 x   13.20  x[  71.85,  88.45] y[ -8.11, -5.60] z[ -32.00, -18.80]
SW-SMD_MST22D18G2_SW-SMD_MST22D -> SW-SMD_MST22D18G2_SW-SMD_ size    6.85 x   5.45 x    9.00  x[ -87.10, -80.25] y[-10.85, -5.40] z[ -31.94, -22.94]
USB-C-SMD_TYPE-C-6PIN-2MD -> USB-C-SMD_TYPE-C-6PIN-2MD       size    7.58 x   4.16 x    8.94  x[ -89.45, -81.87] y[ -8.86, -4.70] z[ -14.94,  -6.00]
CONN-SMD_AFC24-S30FIC-00_CONN-S -> CONN-SMD_AFC24-S30FIC-00_ size   18.60 x   3.15 x    5.40  x[ -10.30,   8.30] y[ -8.80, -5.65] z[  -3.70,   1.70]
LED -> LED                                                   size    0.81 x   0.61 x    1.62  x[ -86.45, -85.64] y[ -6.31, -5.70] z[  -0.81,   0.81]
LED -> LED                                                   size    0.81 x   0.61 x    1.62  x[ -81.65, -80.84] y[ -6.31, -5.70] z[  -0.81,   0.81]
7CUN-PINGXIAN -> 7CUN-PINGXIAN                               size   16.00 x   5.28 x   51.00  x[  -9.00,   7.00] y[ -5.90, -0.62] z[  -0.30,  50.70]
=>[0:1:1:18] -> SOLID                                        size   18.28 x   4.90 x    5.30  x[  -9.14,   9.14] y[ -2.45,  2.45] z[  -0.00,   5.30]
=>[0:1:1:18] -> SOLID                                        size   18.28 x   4.90 x    5.30  x[  -9.14,   9.14] y[ -2.45,  2.45] z[  -0.00,   5.30]
=>[0:1:1:24] -> SOLID                                        size    6.60 x   5.40 x    2.91  x[  -3.30,   3.30] y[ -2.04,  3.36] z[  -0.00,   2.91]
=>[0:1:1:25] -> SHELL                                        size    0.00 x   1.53 x    1.00  x[  -0.00,   0.00] y[  1.83,  3.36] z[   2.01,   3.01]
=>[0:1:1:19] -> SHELL                                        size   16.64 x   0.00 x    1.00  x[  -8.32,   8.32] y[ -0.00,  0.00] z[   5.30,   6.30]
=>[0:1:1:19] -> SHELL                                        size   16.64 x   0.00 x    1.00  x[  -8.32,   8.32] y[ -0.00,  0.00] z[   5.30,   6.30]
USB-C-SMD_TYPE-C-6PIN-2MD -> USB-C-SMD_TYPE-C-6PIN-2MD       size    7.58 x   4.16 x    8.94  x[ -89.45, -81.87] y[ -8.86, -4.70] z[   6.00,  14.94]
SW-SMD_4P-L4_5-W4_5-P3_00 -> SW-SMD_4P-L4_5-W4_5-P3_00       size    4.50 x   4.50 x    7.00  x[  81.95,  86.45] y[-10.20, -5.70] z[  16.75,  23.75]
CN2_CONN-TH_4P-P2_50_4PIN_CONN -> CN2_CONN-TH_4P-P2_50_4PIN_ size    5.70 x  10.01 x   12.50  x[ -86.45, -80.75] y[-12.70, -2.69] z[  25.94,  38.44]
SW-SMD_4P-L4_5-W4_5-P3_00 -> SW-SMD_4P-L4_5-W4_5-P3_00       size    4.50 x   4.50 x    7.00  x[  81.95,  86.45] y[-10.20, -5.70] z[  31.25,  38.25]
TF-SMD -> TF-SMD                                             size   16.15 x   2.66 x   15.20  x[  61.00,  77.15] y[ -7.75, -5.10] z[  34.30,  49.50]
CONN-SMD_2P-P2_00_BX-PH2_0-2PWT -> CONN-SMD_2P-P2_00_BX-PH2_ size    8.01 x   5.60 x    8.50  x[ -76.45, -68.44] y[-11.18, -5.58] z[  41.41,  49.91]
CONN-SMD_2P-P2_00_BX-PH2_0-2PWT -> CONN-SMD_2P-P2_00_BX-PH2_ size    8.01 x   5.60 x    8.50  x[ -60.45, -52.44] y[-11.18, -5.58] z[  41.41,  49.91]
CONN-SMD_2P-P2_00_BX-PH2_0-2PWT -> CONN-SMD_2P-P2_00_BX-PH2_ size    8.01 x   5.60 x    8.50  x[  48.70,  56.71] y[-11.18, -5.58] z[  41.41,  49.91]
H1_HDR-SMD_40P-P2_54-V-F-R2-C20 -> H1_HDR-SMD_40P-P2_54-V-F- size   51.20 x   4.90 x    6.60  x[ -25.60,  25.60] y[ -9.20, -4.30] z[  44.20,  50.80]
35 components

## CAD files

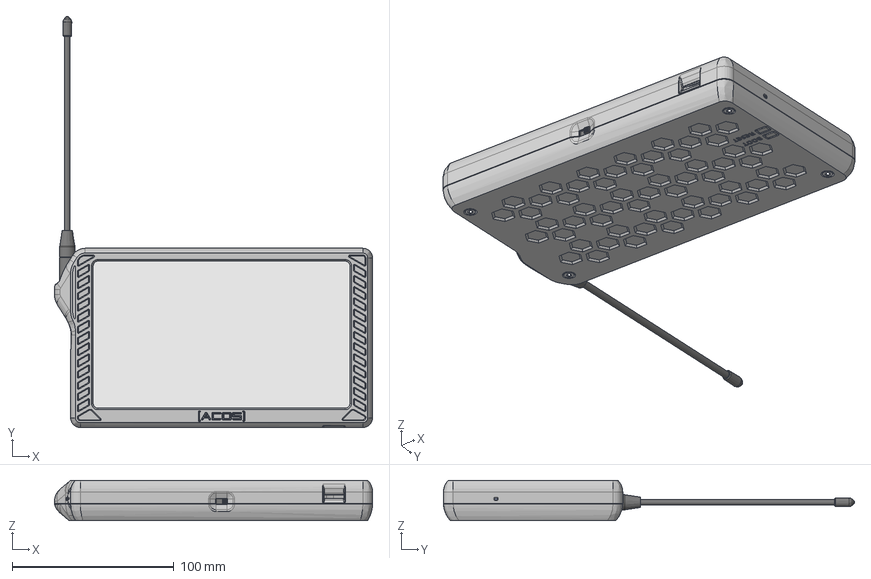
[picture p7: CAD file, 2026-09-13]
cad/community-cases/acos-crowpanel-advance-7-enclosure-s3/acos-crowpanel-7-advance-complete.step
197.0 x 254.5 x 25.0 mm
2-Position_Switch
7_0-PCB-V2_10_1_1_1
BOSS-EXTRUDE7_4__1_1_4_2_1_1
BOSS-EXTRUDE7_5__1_1_4_2_1_1
BOSS-EXTRUDE7_8__1_1_4_2_1_1
BOSS-EXTRUDE7_3__1_1_4_2_1_1
BOSS-EXTRUDE7_7__1_1_4_2_1_1
BOSS-EXTRUDE14_4__1_1_4_2_1_1
BOSS-EXTRUDE14_2__1_1_4_2_1_1
BOSS-EXTRUDE14_8__1_1_4_2_1_1
BOSS-EXTRUDE14_5__1_1_4_2_1_1
BOSS-EXTRUDE7_6__1_1_4_2_1_1
CUT-EXTRUDE5_1_1_4_2_1_1
MIRROR2_1_1_4_2_1_1
BOSS-EXTRUDE7_1__1_1_4_2_1_1
BOSS-EXTRUDE14_10__1_1_4_2_1_1
BOSS-EXTRUDE14_11__1_1_4_2_1_1
BOSS-EXTRUDE14_9__1_1_4_2_1_1
BOSS-EXTRUDE14_6__1_1_4_2_1_1
BOSS-EXTRUDE14_12__1_1_4_2_1_1
BOSS-EXTRUDE14_3__1_1_4_2_1_1
BOSS-EXTRUDE14_7__1_1_4_2_1_1
BOSS-EXTRUDE7_9__1_1_4_2_1_1
BOSS-EXTRUDE7_2__1_1_4_2_1_1
7_0V3_11_1_1_1
7-PIN-PAIMU_7-2_5_5_2_1_1 x 2
GROVE_CONNECTOR__SIT__3-2_1_4_2 x 6
SLIDE-SWITCH_3_6_1_2_1_1
SLIDE-SWITCH_3_6_2_2_1_1
SLIDE-SWITCH_3_6_3_2_1_1
SLIDE-SWITCH_3_6_4_2_1_1
SLIDE-SWITCH_3_6_5_2_1_1
7_0LCD_4_1_1_1
7LCD_4_1_1_1
SMA
Gizont
90751A113_18-8 Stainless Steel Socket Head Screws x 4
90751A111_18-8 Stainless Steel Socket Head Screws x 4

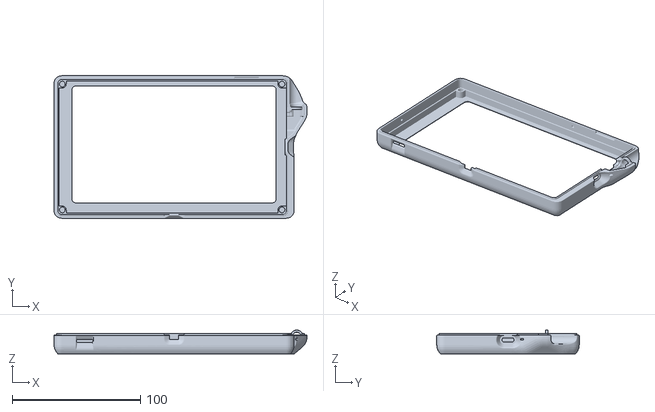
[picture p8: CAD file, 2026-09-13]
cad/community-cases/acos-crowpanel-advance-7-enclosure-s3/acos-crowpanel-7-advance-sma-front-inserts.stl
197.0 x 111.0 x 18.6

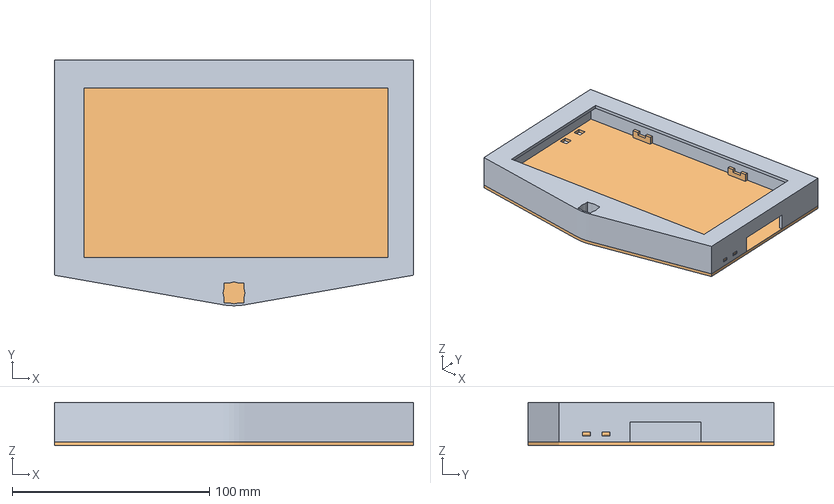
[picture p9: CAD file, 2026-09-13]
cad/community-cases/crowpanel-p4-7in-case-3mf/elecrow-panel.3mf
182.0 x 124.5 x 22.0 mm

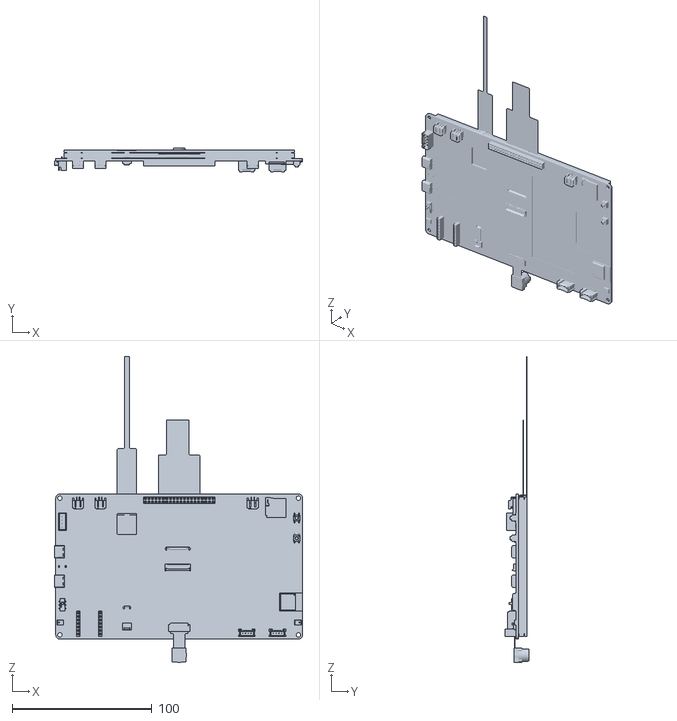
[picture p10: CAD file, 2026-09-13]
cad/crowpanel-advanced-7in-esp32-p4/CrowPanel-Advanced-7in-ESP32-P4.stl
177.9 x 17.5 x 219.2

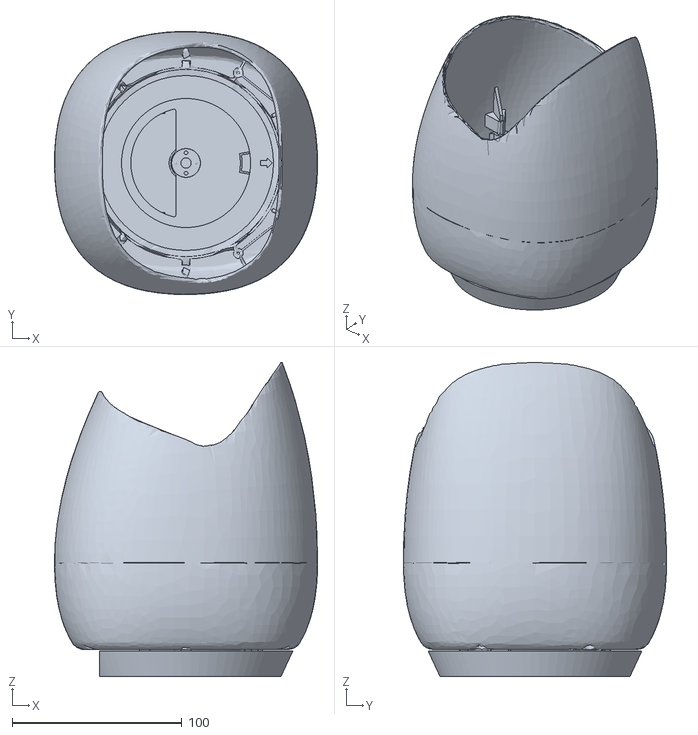
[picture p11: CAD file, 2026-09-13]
cad/reachy-mini/reachy_mini_body.stl
155.0 x 155.0 x 185.0

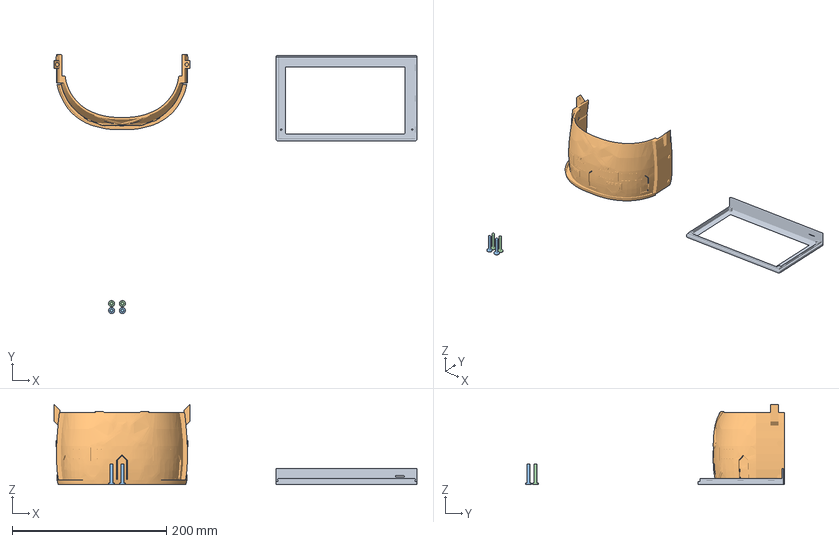
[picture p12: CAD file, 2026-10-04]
hardware/enclosure/out/bambu/reachy-dungarees-bezel-backstrap.3mf
471.0 x 336.4 x 104.3 mm
reachy-crowpanel-bezel
reachy-crowpanel-backstrap
reachy-crowpanel-pins x 2

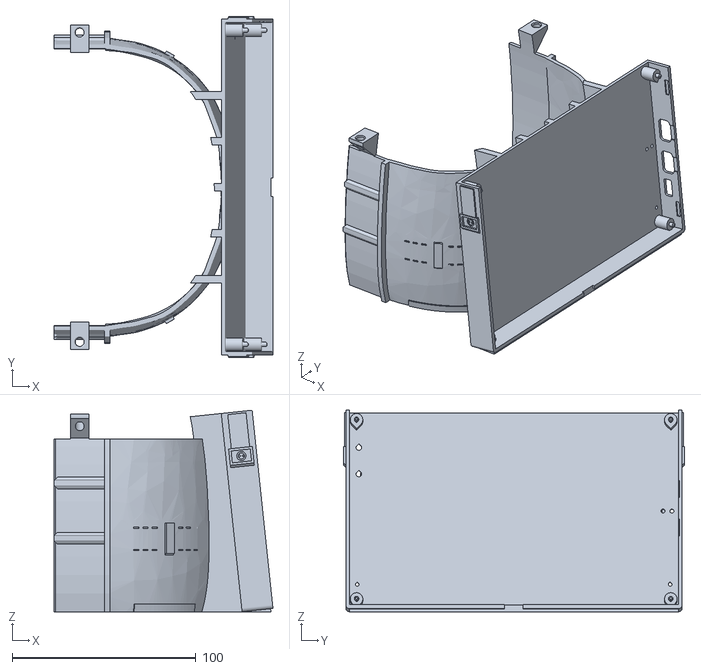
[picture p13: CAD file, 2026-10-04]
hardware/enclosure/out/print/reachy-crowpanel-tray-cradle-print.stl
119.1 x 185.5 x 109.6

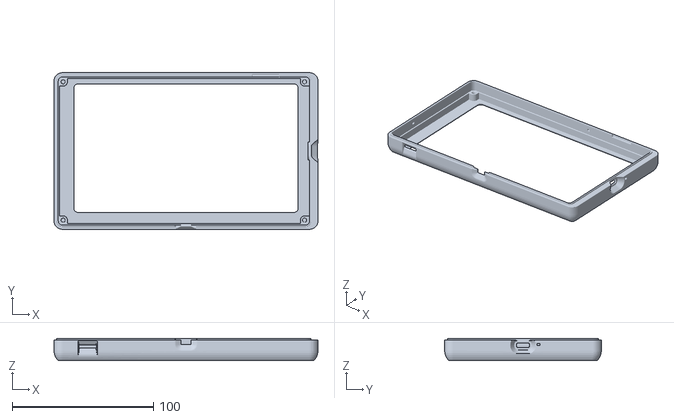
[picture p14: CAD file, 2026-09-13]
cad/community-cases/acos-crowpanel-advance-7-enclosure-s3/acos-crowpanel-7-advance-front.stl
187.0 x 111.0 x 15.8

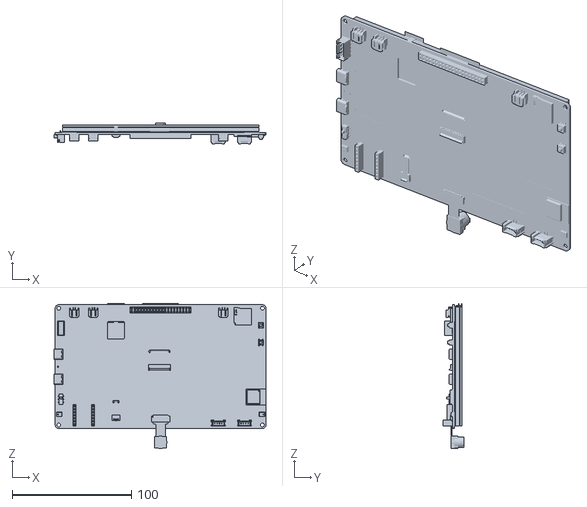
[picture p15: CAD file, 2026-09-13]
cad/crowpanel-advanced-7in-esp32-p4/CrowPanel-Advanced-7in-ESP32-P4_no-flex-tails.stl
177.9 x 17.5 x 121.7

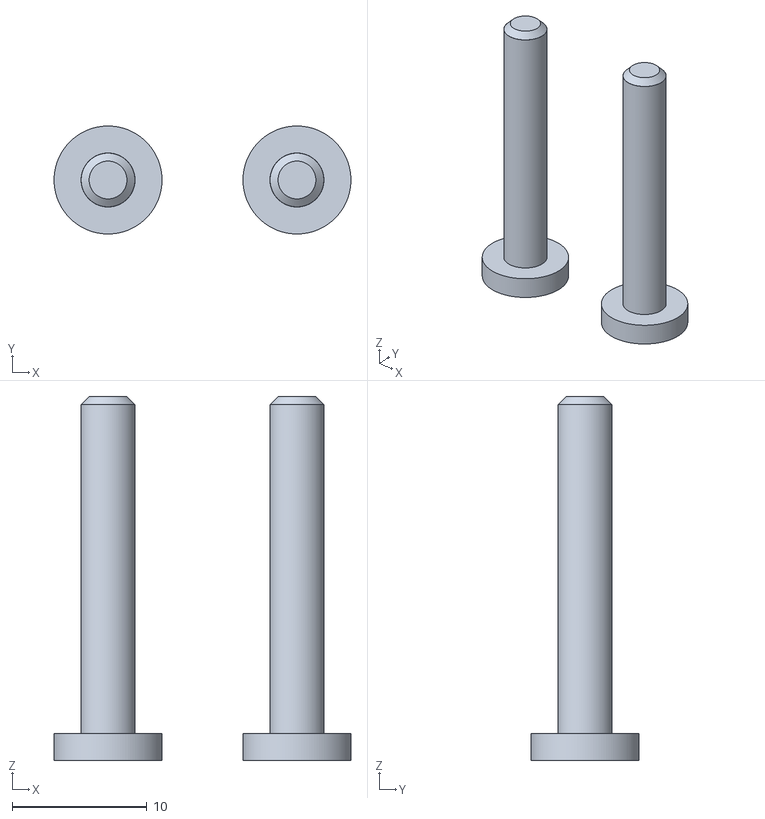
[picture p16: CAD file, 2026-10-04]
hardware/enclosure/out/print/reachy-crowpanel-pins-print.stl
22.0 x 8.00 x 27.0

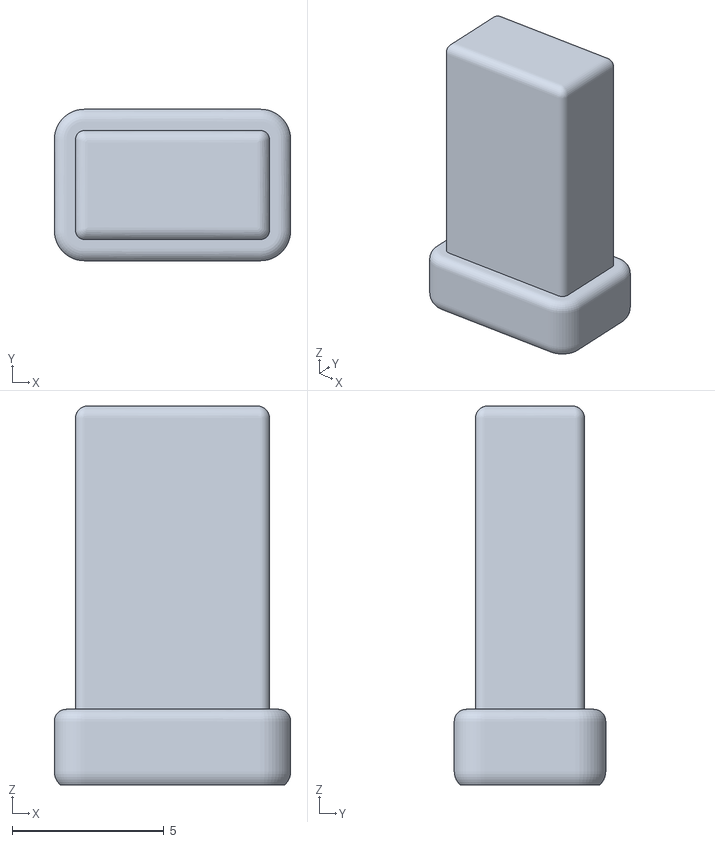
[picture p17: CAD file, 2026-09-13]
cad/community-cases/acos-crowpanel-advance-7-enclosure-s3/acos-crowpanel-7-advance-buttons.stl
7.80 x 5.00 x 12.5

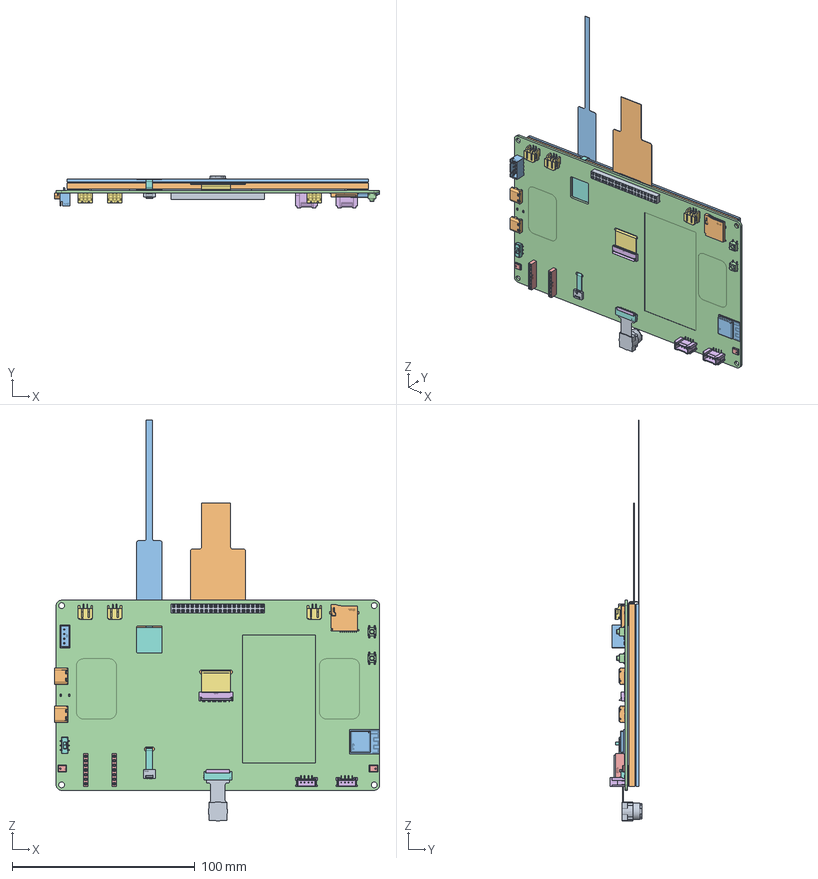
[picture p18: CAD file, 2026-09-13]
cad/crowpanel-advanced-7in-esp32-p4/ESP32-P4-7_0-inch-20251229.stp
177.9 x 17.5 x 219.2 mm
LCD-7CUN
TP-7CUN
PCBA-7CUN
FPC1_FPC-SMD_P0_50-24P_QCHF-SM
H1_HDR-SMD_40P-P2_54-V-F-R2-C20
USB-C-SMD_TYPE-C-6PIN-2MD x 2
CN2_CONN-TH_4P-P2_50_4PIN_CONN
LED x 2
HDR-SMD_7P-P2_54_HX-PM2_54-1X7P x 2
U4_CONN-SMD_4P-P2_00 x 2
CONN-SMD_2P-P2_00_BX-PH2_0-2PWT x 3
SW-SMD_MST22D18G2_SW-SMD_MST22D
FPC-SMD_P0_50-6P_QCHF-SM-H2_0_1
TF-SMD
WIFIM-SMD_61P-L16_6-W13_2-P0_80
SW-SMD_4P-L4_5-W4_5-P3_00 x 2
MIC-SMD_6P-L4_7-W3_8-P1_65-TL_M x 2
CONN-SMD_AFC24-S30FIC-00_CONN-S
7CUN-PINGXIAN
7CUN-TP-XIAN
AS-AG638A32M1-25

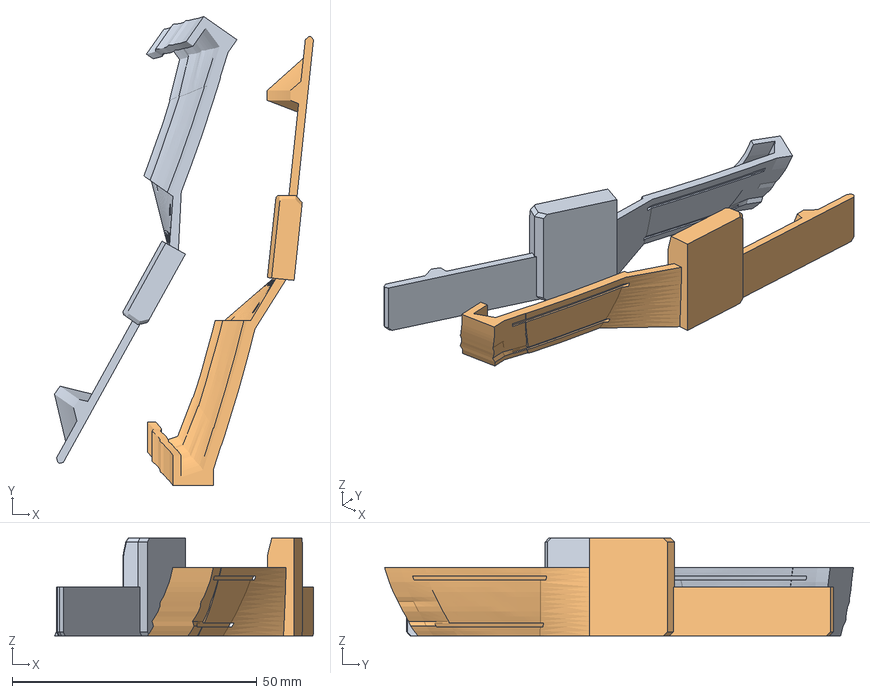
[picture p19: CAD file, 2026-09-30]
hardware/enclosure/out/bambu/reachy-dungarees-bib-straps.3mf
52.9 x 95.8 x 20.0 mm
reachy-crowpanel-bib-strap-left
reachy-crowpanel-bib-strap-right

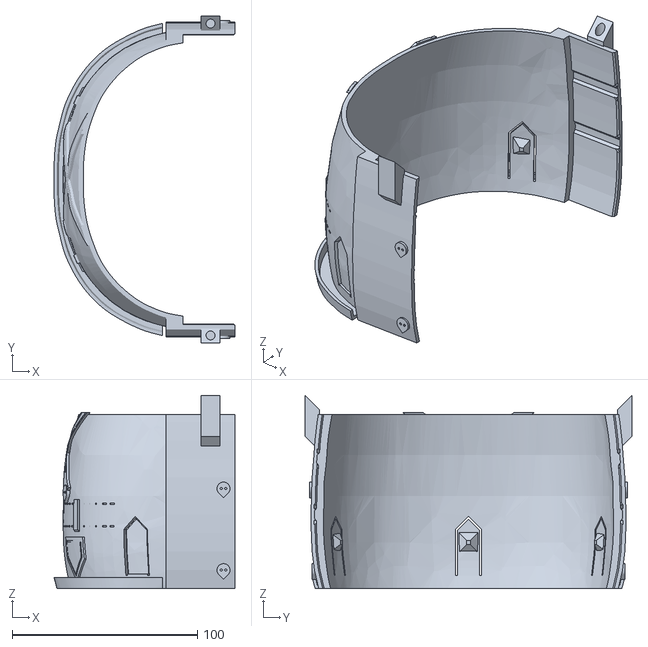
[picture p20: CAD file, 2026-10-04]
hardware/enclosure/out/print/reachy-crowpanel-backstrap-print.stl
97.7 x 176.4 x 104.3

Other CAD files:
hardware/enclosure/out/bambu/reachy-dungarees-tray-cradle.3mf
cad/community-cases/acos-crowpanel-advance-7-enclosure-s3/acos-crowpanel-7-advance-rear.stl
hardware/enclosure/out/print/reachy-crowpanel-bib-strap-left-print.stl
cad/community-cases/acos-crowpanel-advance-7-enclosure-s3/acos-crowpanel-7-advance-center-inserts.stl
cad/community-cases/acos-crowpanel-advance-7-enclosure-s3/acos-crowpanel-7-advance-center.stl
cad/community-cases/acos-crowpanel-advance-7-enclosure-s3/acos-crowpanel-7-advance-front-inserts.stl
cad/community-cases/acos-crowpanel-advance-7-enclosure-s3/acos-crowpanel-7-advance-sma-front.stl
cad/community-cases/acos-crowpanel-advance-7-enclosure-s3/acos-crowpanel-7-advance-sma-rear.stl
cad/community-cases/acos-crowpanel-advance-7-enclosure-s3/acos-crowpanel-7-advance-sma-usb-rear.stl
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

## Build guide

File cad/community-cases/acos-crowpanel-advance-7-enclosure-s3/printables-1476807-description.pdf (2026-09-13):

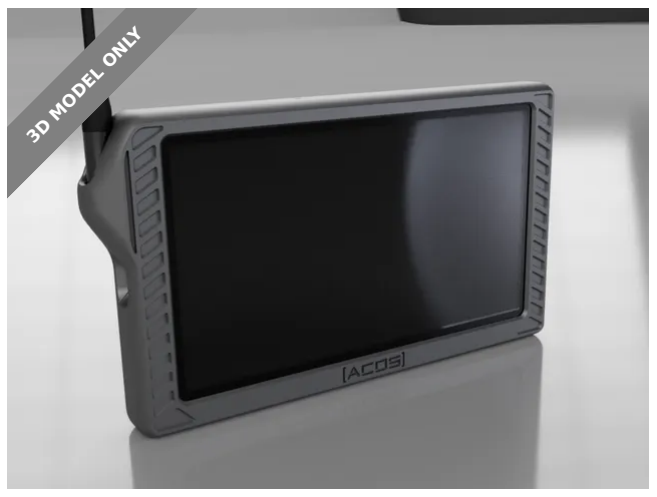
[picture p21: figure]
3D MODEL ONLY

## Summary

[ACOS] Case for the Elecrow Crowpanel Advance 7" ESP32 touchscreen tablet. Space for power switch and 8k lipo. UPDATED!

Hobby & Makers (https://www.printables.com/model?categoryId=48) > Electronics (https://www.printables.com/model?categoryId=52)

Tags: | esp32 | tablet | meshtastic | alleycat | elecrow
crowpanel | acos

Commercial Use and Attribution Notice:

ACOS Design © 2025 by Alley Cat and Majestic AV, LLC. is licensed under CC BY-SA 4.0. (https://creativecommons.org/licenses/by-sa/4.0/)

Commercial use of this design, including promotional use, selling, and reselling to other businesses for sale, is permitted under the following conditions: Prior to any commercial exploitation, you must contact Alley Cat or MajesticAV, LLC to ensure proper attribution. This requirement extends to any sharing, distribution, or creation of derivative works, including manually crafted designs that emulate this design. Proper attribution must be clearly stated in all instances of use. For official contact methods and further information, visit Majestic AV, LLC - Alley Cat. (https://www.majesticav.com/alleycat/) Any other sources are unauthorized and should not be used for commercial or licensing inquiries.

Alley Cat (https://www.printables.com/@AlleyCat)

## Elecrow Crowpanel Advance 7 Enclosure

VIEW IN BROWSER (https://www.printables.com/model/1476807-elecrow-crowpanel-advance-7-enclosure)

updated 29. 8. 2026 | published 29. 8. 2026

Disclosure: Some links on this page may be Amazon or their respective company affiliate links. If you make a purchase through them, I may earn a small commission at no extra cost to you. I only recommend gear I trust and use myself. Thanks for your support!

Suggested Print Settings:

Material: PLA+ or PETG
Nozzle: 0.4mm
Extrusion Width 0.4mm
Layer Height: 0.2mm
Perimeters: 3
Infill: 20% Gyroid
Top/Bottom Layers: 5
Support Material: None

3D Printing Disclaimer:

Thank you for downloading my CAD design! I want to assure you that extensive testing and iteration went into creating this design. However, please keep in mind that 3D printing involves a wide range of variables, including different types of filament, printer settings, and calibration levels. These factors can significantly impact the final print.

Before concluding that the design is flawed, I encourage you to:

- Check your printer calibration: Ensure your printer is properly calibrated. Calibrate filament shrinkage!
- Adjust print settings: Try changing the print settings to achieve better results.
- Resize the model: Scaling the model up or down slightly may resolve fit issues.

Remember, these are development boards and sometimes have very fragile parts. If you encounter any issues or need assistance, please feel free to reach out to me. I am here to help and can provide guidance to achieve the best results. Claiming a design is bad without considering these variables does a disservice to the community and may discourage others from trying a design that could work perfectly with minor adjustments.

Thank you for your understanding and cooperation. Happy printing!

## Model files

Description:

UPDATE 14FEB2026: Added the non SMA version.

Custom case for the Elecrow CrowPanel Advance 7“ HMI ESP32-S3 AI-Powered IPS Touch Screen. (https://www.elecrow.com/crowpanel-advance-7-0-hmi-esp32-ai-display-800x480-artificial-intelligent-ips-touch-screen-support-meshtastic-and-arduino-lvgl-micropy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) Requires 4x M3x8mm screw and 4x M3x12mm screws. Here are links to the parts I used:

Elecrow Crowpanel Advance 7" Direct from Elecrow (https://www.elecrow.com/crowpanel-advance-7-0-hmi-esp32-ai-display-800x480-artificial-intelligent-ips-touch-screen-support-meshtastic-and-arduino-lvgl-micropy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)

8000mAh MakerNova LiPo Direct (https://makernova.io/products/makernova-8000mah-rechargeable-battery-with-jst-1-25-connector-for-meshtastic-heltec-lilygo-arduino-and-other-devices) / Amazon (https://amzn.to/4gvgyvW)

17cm SMA Antenna Direct (https://makernova.io/products/gizont-915mhz-17cm-whip-antenna-with-ipex-cable-for-lora-and-meshtastic) / Amazon (https://amzn.to/4y51g8l)

Perfect Fit Folding Antenna (https://amzn.to/44GL5Bh)

Will not fit an antenna with bigger than 11mm base

Right Angle SMA (https://amzn.to/4jlB3L0)

Heat Set Inserts (https://a.co/d/ifgnTht)

Power Switch (https://amzn.to/4dz6Irg) or Power Switch (https://amzn.to/4qTKd6X)

Assembly Video:

https://www.youtube.com/watch?v=2JuRoskbhio

- For Heat Set Inserts
- Same but no SMA
- Screw threads into plastic acos-crowpanel-7-advance-sma-front-inserts.stl

acos-crowpanel-7-advance-front-inserts.stl

acos-crowpanel-7-advance-sma-front.stl

- Same but no SMA
- For Heat Set Inserts
- Screw threads into plastic
- Print two of these
- For RF expansion that has a USB
- Same but no SMA
- No USB on top
- Same but no SMA
- STEP file so you can modify the design. CC BY-SA 4.0 still applies.

acos-crowpanel-7-advance-front.stl

acos-crowpanel-7-advance-center-inserts.stl

acos-crowpanel-7-advance-center.stl

acos-crowpanel-7-advance-buttons.stl

acos-crowpanel-7-advance-sma-usb-rear.stl

acos-crowpanel-7-advance-usb-rear.stl

acos-crowpanel-7-advance-sma-rear.stl

acos-crowpanel-7-advance-rear.stl

acos-crowpanel-7-advance-complete.step

## License

This work is licensed under a
Creative Commons (4.0 International License)

Attribution-ShareAlike (http://creativecommons.org/licenses/by-sa/4.0/)

✖ | Sharing without ATTRIBUTION
✔ | Remix Culture allowed
✔ | Commercial Use
✔ | Free Cultural Works
✔ | Meets Open Definition

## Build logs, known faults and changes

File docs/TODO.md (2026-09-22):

# TODO: hardware ideas not yet built

What might come next for the plastic, and what has already been measured for it. The enclosure's
own open risks stay where they are, in
[`hardware/enclosure/README.md`](../hardware/enclosure/README.md) under "Open risks" - this file is
for things that do not exist yet.

Nothing here has been printed, modelled or committed to. Numbers below were read off Pollen's mesh
(`cad/reachy-mini/reachy_mini_full.stl`) on 2026-09-22; anything not measured says so.

## 1. A hat

Asked for 2026-09-22: something with more character on the head, that does not get in the way of the
antennas or the microphones.

### What the head gives you (measured, robot frame R)

The head runs from the body's rim at **z 185** up to a crown that closes at about **z 252**. It is
wider than it is deep: roughly **94 mm front-to-back** (x +43.6 at the face, -52.3 at the back) and
**150 mm side-to-side** (|Y| up to 75.0). The face is flat-ish in X from z 190 to 226 and then
curves away.

| z | max radius | x front | x back | max \|Y\| |
|---|---|---|---|---|
| 190 | 77.4 | 42.3 | -50.8 | 74.9 |
| 200 | 77.5 | 43.6 | -51.5 | 75.0 |
| 210 | 77.1 | 43.0 | -51.3 | 75.0 |
| **220** | **79.7** | 41.5 | -52.3 | 74.4 |
| 230 | 78.2 | 39.9 | -50.8 | 72.8 |
| 240 | 70.0 | 36.9 | -38.4 | 67.3 |
| 245 | 73.6 | 33.5 | -45.0 | 60.5 |
| 250 | 42.9 | 24.2 | -7.5 | 39.6 |

**The bulge at z 220-225 is real but shallow, and it is not the belly.** The collar works because
the body's widest ring has 3-4 mm of taper on both sides of it; here there is only **2.3 mm of
taper below** (77.4 at z 190 against 79.7 at z 220) against a strong narrowing above. So a band on
the bulge is held well against riding **up** and hardly at all against creeping **down** - it would
need friction (TPU), a lip, or something hooked over the crown. *(Said the other way round in chat
first; the table is what to believe.)*

### The antennas are the hard constraint

Two stalks, |Y| **52.6..62.0**, x **-44.8..-34.9**, rising from about **z 258**; the tip at z 390 is
only 3.4 x 3.5 mm, at x -27..-24. They emerge **behind** the crown.

Two things make them worse than they look:

- **The CAD only has the zero pose.** The full mesh has almost no triangles between z 290 and 365,
  so even the static stalk is barely modelled - base and tip, little between.
- **The sweep is enormous.** The sibling repo's CLAUDE.md records that in the sleep pose the
  antennas pass about **14 mm outside the collar top**, and the collar top is z 124. So they travel
  from vertical (z 390) all the way down alongside the head. Any crown, and any band closed at the
  back, is somewhere in that arc.

**Nothing should be designed against the zero pose.** Drive the antennas through their range, record
the envelope, and design against that.

### Settle these two before covering anything

1. **Where the microphone ports are.** The XVF3800 array is in the head (`head_mic_3dprint` on the
   `xl_330` link) and direction-of-arrival is load-bearing - it is how she turns to whoever spoke.
   Not visible in the mesh. Cheap test: tape a blank ring or cap blank on, play a sound from a known
   bearing, and compare `GET /api/state/doa` with and without it. That is a fact rather than a guess.
2. **The antenna sweep**, as above.

Also unmeasured: **what the Stewart platform will carry.** Six small servos, and a hat is mass at the
end of the lever. There is no payload figure anywhere in either repo. Keep it light and low, and say
so rather than assuming.

### Options, by how much they risk

**Low risk - nothing over the mics, nothing in the antenna arc**

| Idea | Why it is safe | Notes |
|---|---|---|
| **Hatband on the bulge** | A **C**, open at the back, so drooping antennas clear it. No crown. | On its own it reads as a sweatband. Its real job is to be the mount for everything below. Needs the creep problem solved (see above). |
| **Carpenter's pencil behind the ear** | A flat pencil tucked into that band, nothing else. | The most in-character object this robot could own, and about 2 g. |
| **Flat cap, worn forward** | Crown only on the front half (x +40 back to about -10); the antennas emerge behind it whatever they do. | Maximum workwear, minimum risk. Check the peak against the camera's upward field of view. |
| **Visor** | Brim and band, no crown at all. | Green translucent eyeshade, or matte for the workshop. Weighs nothing. |
| **Ear defenders, pushed up or slung round the neck** | Funny *because* they are not covering anything. | The "just clocked off" look. |

**Higher risk - charming, but only after the microphone test**

| Idea | What it costs |
|---|---|
| **Beanie with antenna slots** | Antennas poke through like ears. The crown covers whatever is on top, and the slots must fit the whole sweep, not the zero pose. |
| **Hard hat** | Perfect with dungarees. Tallest and heaviest option, all of it cantilevered on the platform. |
| **Bandana knotted at the back** | The knot lands exactly where the antennas live. |

### The one worth pursuing

**Make the band the product and the hats swappable.** Solve the hard part once - a light C-band that
stays put on the bulge, open at the rear, verified against DOA and against a measured antenna sweep -
then give it a dovetail or peg so toppers clip on: flat cap, visor, pencil, flower, party hat, beret,
Santa hat in December. The risky interface is tested a single time; after that each new hat is a
twenty-minute print with no new risk to the antennas, the microphones or the servos.

Two things to carry into whichever one wins:

- **Light and low.** See the unmeasured payload above.
- **Its own colour.** The AMS height-range trick already documented for the cuff and waistband
  (enclosure README, "Printing") would let a brown cap read as a separate garment rather than as
  more enclosure. The dungarees' own language - dashed stitching, teardrop buttons - is what will
  make it look designed rather than bolted on.

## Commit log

2026-09-13 Reachy Mini dungarees enclosure for the CrowPanel Advanced 7in ESP32-P4
    cadquery source for a three-part screwless PETG enclosure that clamps the
    display onto Reachy Mini's belly, with fit, mesh, layer/overhang and slicer
    checks, a Bambu Studio project writer, renders, and reference CAD (Reachy
    Mini body from Pollen's URDF meshes, the ACOS community case).
    Build outputs and the Elecrow STEP are not included in this commit.
    [acos-crowpanel-7-advance-buttons.stl, acos-crowpanel-7-advance-center-inserts.stl, acos-crowpanel-7-advance-center.stl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]
2026-09-13 Add Elecrow CrowPanel P4 reference CAD and community case 3MF
    Elecrow's official ESP32-P4 7in STEP (from their GitHub repo) with STL
    conversions and part dimensions, and the downloaded two-part case 3MF.
    [CrowPanel-Advanced-7in-ESP32-P4.stl, CrowPanel-Advanced-7in-ESP32-P4_no-flex-tails.stl, ESP32-P4-7_0-inch-20251229.stp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]
2026-09-20 CLAUDE.md for the hardware repo, and commit the v0.5 review with its printable results
    Written as a handover, so the next agent can change the geometry without rediscovering the rules:
    the CAD interpreter is `python` (3.11, cadquery 2.8) and not `py -3.12`; out/ is generated and never
    hand-edited; every fit number belongs to a class in geom.py; walls are whole line widths and heights
    whole layers in the part's own print orientation; every underside 45 degrees or steeper and no
    bridged roof over a flexure; and the four checks plus a solo slice are what "done" means, with the
    README's Status section as the record. It also lists what each script proves, where each number
    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
    [reachy-crowpanel-backstrap-print.stl, reachy-crowpanel-bezel-print.stl, reachy-crowpanel-tray-cradle-print.stl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]
2026-09-22 Bib straps: two clip-on shoulder straps, and nothing else touched
    The dungarees had no front straps, so the robot read as carrying a bib rather
    than wearing one. overalls.py adds two small prints that hang over the robot's
    own front rim, run down the outside of the shell, and tuck into the gap behind
    the display, where they hook over the bezel's top rear corner. Nothing touches
    the bib's face and none of the three existing parts changed - enclosure.py was
    not re-run.
    Held down by gravity in the rim hook and located by the bezel hook; in between
    the strap is trapped in a gap 10-13 mm wide, so neither hook has to grip. The
    rim slot is a loose 4.5 mm over a rim measured at ~2 mm, on purpose: a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
    [reachy-crowpanel-bib-strap-left-print.stl, reachy-crowpanel-bib-strap-right-print.stl, reachy-dungarees-bib-straps.3mf]
2026-09-22 Sections through the bib strap, because a 3-D render cannot show a 1 mm gap
    render_overalls.py now cuts every part with the plane robot Y = 36.37 and draws
    the outlines filled: the whole strap, and the two hooks enlarged. That is what
    shows the fit - the C sitting on the shell's top edge, the 1.5 mm the run stands
    off the body, the hook straddling the panel's top rear corner with 0.4 mm either
    side, and the bib's face with nothing on it.
    Two bugs in the sectioning, both of which made the drawing lie about geometry
    that is fine:
    - The loop walker marked NODES seen and only walked forward, so it cut every
    closed loop into pieces wherever it happened to start. At Y 36 the strap came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
2026-09-22 Bib straps v2: the foot sits in a pocket the cradle already had
    The owner pointed at the gap behind the panel and asked to mount there,
    because the gaps are already anchors. They are: the ribs at |Y| 25 and 50
    leave a slot 27.10..47.90, 20.80 wide, and their top edges are a flat bearing
    plane at board z 53.6. So the foot has two SHOULDERS that bed on the rib tops
    and a TONGUE that hangs in the slot, with the panel's back face in front and
    the shell behind. The mount locates the strap in all three directions and
    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
    [reachy-crowpanel-bib-strap-left-print.stl, reachy-crowpanel-bib-strap-right-print.stl, reachy-dungarees-bib-straps.3mf]
2026-09-22 Bib straps: clear the v1 leftovers out of the docs and the constants
    A read-through after v2 landed. No geometry change - the part rebuilds to the
    same 2.49 cm3 and the same extents.
    - README said bib-strap-right was 2.07 cm3. It is 2.49, same as the left;
    2.07 was v1's.
    - to_bed's docstring still quoted v1's slice (28 min, 5.5 g) and v1's
    overhang figures. It now says 39 min / 6.0 g, 91 mm2 over 45 deg, 135 mm2
    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
2026-09-22 docs/TODO.md: hat options, and what the head actually allows
    Ideas only - nothing modelled, nothing printed. Written down because the
    measuring is the part worth keeping.
    Read off Pollen's full mesh on 2026-09-22:
    the head runs z 185 to a crown closing at ~252, about 94 mm front-to-back
    and 150 side-to-side, face flat in X from z 190 to 226
    the antennas are two stalks at |Y| 52.6..62.0, x -44.8..-34.9, rising from
    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
2026-09-30 Bib straps v3: deeper foot with a spring finger, so they hold without glue
    v2 located the straps but nothing held them; the printed pair needed hot glue.
    v3 drops the shoulders, runs the tongue down the slot between the cradle ribs
    to just over the collar band, and adds a spring finger (outboard half) down
    between the tray's back wall and the band. Its nub presses the band, clamping
    the strap between two faces of the tray-cradle. No change to the three
    existing parts.
    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
    [reachy-crowpanel-bib-strap-left-print.stl, reachy-crowpanel-bib-strap-right-print.stl, reachy-dungarees-bib-straps.3mf]
2026-09-30 Bib straps: first-layer adhesion settings on their plate; v3 confirmed printed
    The first v3 print would not stay on the plate and the PETG built up on the
    nozzle. The bib-straps plate alone now prints its first layer at 25 mm/s
    (was 50, 105 for infill) and 255 C (was 245), on a textured plate at 80 C for
    the first layer and 75 C after (was 70), with 8 mm brims (was 5). Temperatures
    are recorded as filament-group changes. Slices in 41 min / 9.1 g, no warnings.
    The owner has printed the v3 straps and they fit and hold without glue.
    [reachy-dungarees-bib-straps.3mf]
2026-10-04 Enclosure v0.6: the side joints are a rail-and-pin slide lock
    v0.5 was printed and its flex-tab joint hooks never clicked (the owner glued it, 2026-09-30). Each side
    now has two trapezoid rails on the tray-cradle's side plate running in grooves in the backstrap's tongue,
    a stop, and a 4 mm pin dropped through a cap (tray-cradle) into a boss (tongue); nothing has to flex.
    Joint clearances FIT_JOINT 0.50 a side, pin hole 4.8 mm. Two pins print head-down on the bezel-backstrap
    plate (out/print/reachy-crowpanel-pins-print.stl).
    Checked in CAD: 0.000 mm3 interference everywhere, the backstrap's path 0.5-100 mm along the rails, stop
    and pin positive controls, watertight, islands clean. Sliced: tr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
    [reachy-crowpanel-backstrap-print.stl, reachy-crowpanel-pins-print.stl, reachy-crowpanel-tray-cradle-print.stl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]
